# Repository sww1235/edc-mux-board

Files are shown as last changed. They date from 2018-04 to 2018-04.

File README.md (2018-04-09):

# EDC-MUX-Board

This is part of the [EDC harness
project](https://github.com/sww1235/edc-harness) and provides, audio and PTT
routing and control routing.

Will also potentially allow for audio priority ducking
via the [mixer](https://github.com/sww1235/portable-line-mixer).

All audio IO is done at consumer line level. (IO direction is referenced to MUX)

Connected headphones will accept this as there is also an integrated amplifier.
(Headset output)

Connected phones and radios inputting audio into the mux will also work fine as
they output line level. (Device input)

Electret microphones need a bias circuit and a preamp to boost their signal up
to line level. (headset input) as well as a capacitor to block the DC bias output

Connected phones and radios will need a pad circuit to reduce the line level
output to a microphone input as well as block dc output from phone/radio.
(Device Output) Resistor divider with ~40dB attenuation. Attenuation in dB = 20*
log10((R1 + R2)/R2). Also need resistance between bottom two sleeve contacts.

o-----^v^v^v--|---o
      R1      >
Line          < mic
          R2  >
              >
o-------------|---o

## Extra parts

-   EN3P8MCX switchcraft 8pin male panel mount connectors (use MPX 3d model)
-   EN3C8FCX switchcraft 8pin female cable connection
-   CARAEN3C8F07990 switchcraft 8pin female right angle pre-terminated cable
-   EN3CAPC  cord plug connector cover
-   EN3CAPX   panel mount connector cover
-   772-E25-103RYY1 norcomp db25 IP67 connector male
-   772-E25-203RYY1 norcomp db25 IP67 connector female (for panelmount)
-   967-025-010R011 norcomp db25 IP67 backshell for cable
-   SFP6725 norcomp adhesive seal db25 size
-   967-025-CAP norcomp ip67 sealing cap
-   160-067-004R034 norcomp db25 hardware kit
-   767KS1(X) 0.084 \[2.1\] id/od sealed locking power plug switchcraft
-   L722AS 0.08 \[2.0\] id/od sealed locking power jack switchcraft (these sizes are compatible with high amperage version
-   JCAP  power jack cover
-   35FM3AULS - Sealed locking 3.5mm panel mount jack switchcraft
-   35HDLBAU(S) 3.5mm sealed locking plug switchcraft (S=0.175 diameter cable, no S=0.29 diameter cable)
-   NE8FDX-P6-W IP rated ethercon connector Cat6A shielded neutrik
-   NE8MX6 Cat6A ethercon cable connector neutrik

## TODO

-   CODE
-   Case
    -   Change lid screws to M2.5
    -   Move Oring inside screw line (use same as on portable line mixer)
    -   weight reduction on chassis and lid. Shrink wall thickness to 0.125", leave ribs on base for stiffness
    -   leave sealing flange and ribs on lid
    -   leave connector sides full thickness

## Power Consumption

| Quantity | Description | Part Number | Individual Power Consumption |
|:---|:---|:---|:---|
| 3 | IO expanders | TCA9555 | 56uA \@5V |
| 6 | IO expanders | TCA9555 | 35uA \@2V5 |
| 24 | 8:1 Mux | ADG708 | 1uA max \@±2V5 (both rails) |
| 8 | 8:1 Mux | ADG708 | 1uA max \@5V |
| 3 | SPST switch | ADG715 | 25uA max \@±2V5 (both rails) |
| 4 | 4x SPDT switches | ADG734 | 1uA max \@±2V5 (both rails) |
| 72 | 4x op amp | OPA1604 | 2.8mA \@±12VA (both rails) |
| 21 | 2x op amp | OPA1602 | 2.6mA \@±12VA (both rails) |
| 12 | 2x digi pot | DS1882 | 1uA \@5VD, 2.5uA \@±5VA |
| 2 | OR gate | SN74ACT32 | 20uA \@5V |
| 2 | SPST switch | TS12A44514 | 0.2uA \@12V |
| Total | ±2V5 rail || 313uA (rounded ->) 0.5mA |
| Total | ±12VA rail || 256.2mA (rounded ->) 500mA |
| Total | ±5VA rail | | 30uA |
| Total | +5V rail | | 2\*2V5\* 0.5mA = 2.5mW \@5V = 0.5mA (assume at least 10mA) + </br>2\*5VA\* 30uA = 0.3mW \@5V = 60uA (assume at least 10mA) + </br>228uA -> 0.5mA </br> Sum = 0.5mA + 0.5mA + 60uA = 1.06mA (assume 30mA) = 6mA \@12V |
| Total | 12V+12VA rail | | 518.4mA (rounded ->) 1A (includes 2v5 and 5V conversions) |

## References

-   <http://www.epanorama.net/circuits/line_to_mic.html>
-   <http://www.n1gy.com/headset-adaptor.html>
-   <http://www.mobilinkd.com/category/hacking/>
-   <http://ham.stackexchange.com/questions/5244/2-pin-kenwood-to-sound-card-beofeng-uv-82hp-asus-xonar-essence-stx>
-   <http://uuki.kapsi.fi/dl/uv5r_spkmic.pdf>
-   <http://www.n1gy.com/headset-adaptor-for-kenwood--baofeng-and-wouxun-hts.html>
-   <http://electronics.stackexchange.com/questions/71335/how-to-amplify-electret-microphone-to-range-from-0-5v-with-bias-of-2-5v>
-   <https://www.invensense.com/wp-content/uploads/2015/02/Using-a-MEMS-Microphone-in-a-2-Wire-Microphone-Circuit.pdf>
-   <http://www.brenorbrophy.com/HG/head_set_ptt.htm>
-   <http://electronics.stackexchange.com/questions/25229/do-electret-condenser-microphones-require-phantom-power>
-   <http://electronics.stackexchange.com/questions/27452/coupling-electret-microphone-input-to-linear-audio-output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>
-   <http://electronics.stackexchange.com/questions/261258/electret-microphone-how-does-it-work?rq=1>
-   <https://forums.radioreference.com/radio-direction-finding-forum/297920-baofeng-foxhunt-transmitter.html>
-   <https://www.reddit.com/r/amateurradio/comments/2jd4wr/line_level_to_high_impedance_input/>
-   <http://electronics.stackexchange.com/questions/176941/microphone-connection-diagram>
-   <http://i.stack.imgur.com/BMmRJ.jpg>
-   <http://www.dotmana.com/weblog/wp-content/uploads/Kenwood-Ham-Speaker-Jack-Wiring-Schematic.png>
-   <http://forums.qrz.com/index.php?threads/aprsdroid-cable-for-rx-and-tx-on-baofeng-hts.486407/>
-   <http://n4ser.org/2015/aprs-tracker-the-project-phase-2-io/>
-   <http://ham.stackexchange.com/questions/5023/mic-ground-vs-ground>
-   <http://www.circuitbasics.com/how-to-hack-a-headphone-jack/>
-   <http://www.faberacoustical.com/forum/index.php/topic,123.0.html>
-   <http://electronics.stackexchange.com/questions/38452/electronic-aspects-of-iphone-3-5mm-audio-output>
-   <http://www.echoireland.com/Interface/PTT_to_Computer_Information.pdf>
-   <http://electronics.stackexchange.com/questions/22486/help-with-ptt-circuit-for-icom-radio>
-   <http://electronics.stackexchange.com/questions/176442/what-is-the-wiring-for-a-pull-down-resistor-on-the-or-gate>

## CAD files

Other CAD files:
case/edc-mux-board-housing.FCStd

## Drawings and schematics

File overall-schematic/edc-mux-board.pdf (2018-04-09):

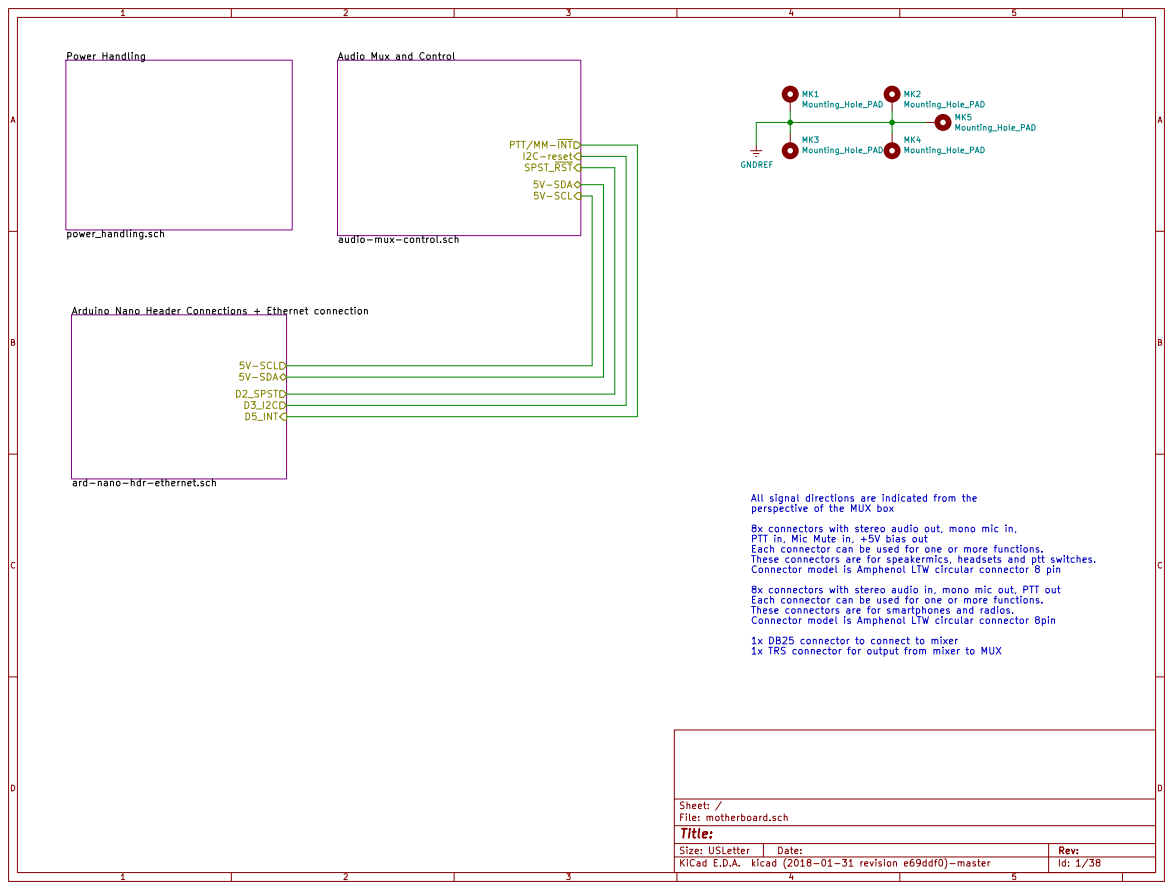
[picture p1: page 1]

Audio Mux and Control audio-mux-control.sch

Arduino Nano Header Connections + Ethernet connection

ard-nano-hdr-ethernet.sch

All signal directions are indicated from the
perspective of the MUX box
8x connectors with stereo audio out, mono mic in,
PTT in, Mic Mute in, +5V bias out Each connector can be used for one or more functions. These connectors are for speakermics, headsets and ptt switches.

Connector model is Amphenol LTW circular connector 8 pin
8x connectors with stereo audio in, mono mic out, PTT out Each connector can be used for one or more functions. These connectors are for smartphones and radios.

Connector model is Amphenol LTW circular connector 8pin
1x DB25 connector to connect to mixer 1x TRS connector for output from mixer to MUX

Id: 1/38 Title: File: motherboard.sch Sheet: /

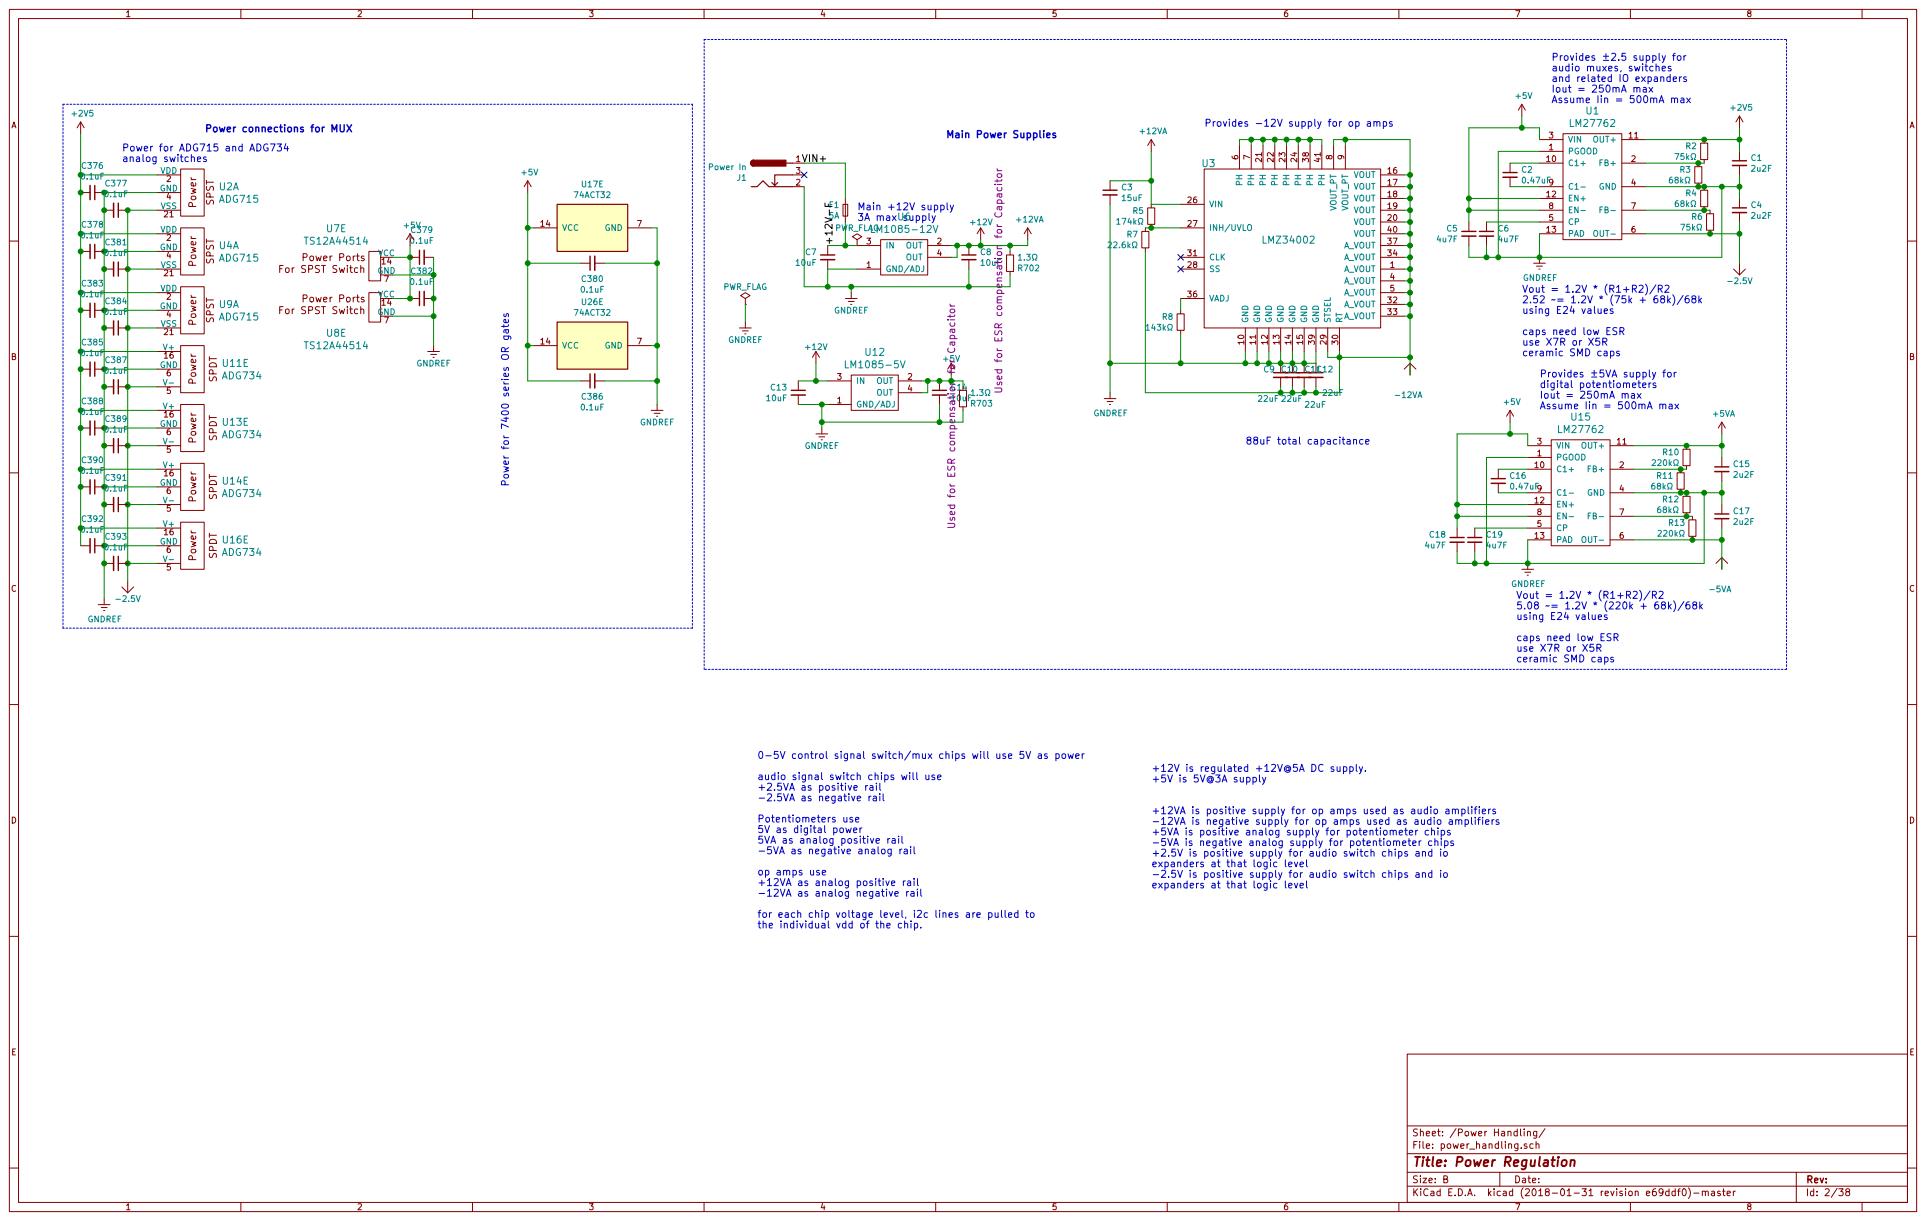
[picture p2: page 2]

Provides ±2.5 supply for
audio muxes, switches
and related IO expanders
Iout = 250mA max Assume Iin = 500mA max Vout = 1.2V * (R1+R2)/R2

Provides -12V supply for op amps R702

Iout = 250mA max Assume Iin = 500mA max Power for ADG715 and ADG734
analog switches

0.1uF C377 0.1uF C385 | 2VSS

Vout = 1.2V * (R1+R2)/R2
using E24 values
caps need low ESR
use X7R or X5R
ceramic SMD caps
Provides ±5VA supply for
digital potentiometers

0.1uF C387 | 21 GND

1.3 Used for ESR compensation for Capacitor

0.1uF C390 | 16V-5 GND

16V-5 GND

0-5V control signal switch/mux chips will use 5V as power
audio signal switch chips will use
+2.5VA as positive rail
-2.5VA as negative rail Potentiometers use 5V as digital power

+12V is regulated +12V@5A DC supply.
+5V is 5V@3A supply

+12VA is positive supply for op amps used as audio amplifiers
-12VA is negative supply for op amps used as audio amplifiers
+5VA is positive analog supply for potentiometer chips
-5VA is negative analog supply for potentiometer chips
+2.5V is positive supply for audio switch chips and io
expanders at that logic level
-2.5V is positive supply for audio switch chips and io

5VA as analog positive rail
-5VA as negative analog rail op amps use +12VA as analog positive rail

-12VA as analog negative rail
for each chip voltage level, i2c lines are pulled to
the individual vdd of the chip.

Sheet: /Power Handling/
File: power_handling.sch
Id: 2/38 Title: Power Regulation

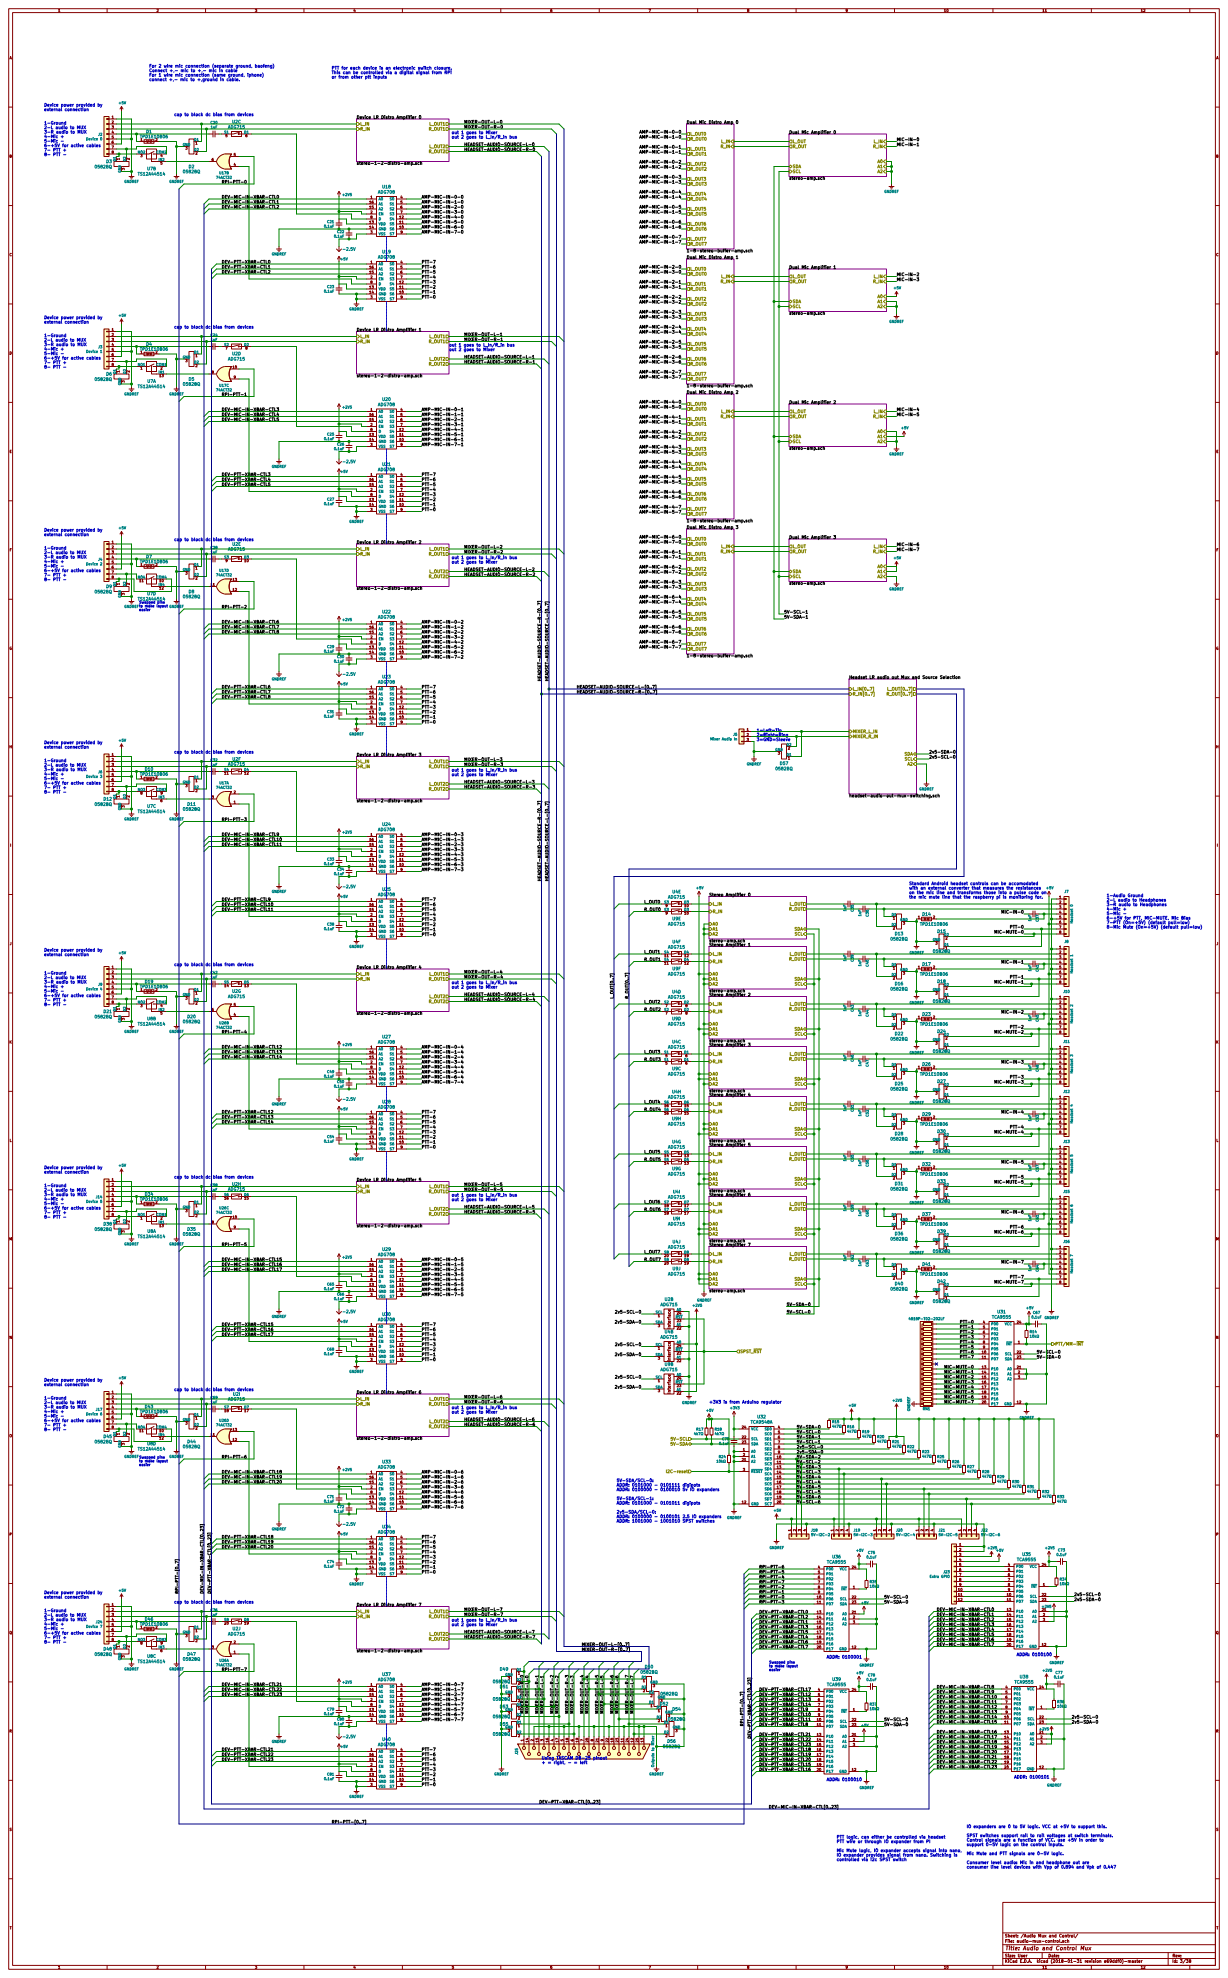
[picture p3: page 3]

For 2 wire mic connection (separate ground, baofeng)
Connect +,- mic to +,- mic in cable
For 1 wire mic connection (same ground, iphone)

or from other ptt inputs

cap to block dc bias from devices

MIXER-OUT-L-0
MIXER-OUT-R-0
out 1 goes to Mixer
out 2 goes to L_In/R_in bus
HEADSET-AUDIO-SOURCE-L-0
HEADSET-AUDIO-SOURCE-R-0

1-Ground
2-L audio to MUX
3-R audio to MUX
4-Mic +
5-Mic - 6-+5V for active cables 7- PTT +

Dual Mic Distro Amp 0

RPI-PTT-0 RPI-PTT-1 RPI-PTT-2 RPI-PTT-3 RPI-PTT-4 RPI-PTT-5 RPI-PTT-6 RPI-PTT-7 RPI-PTT-[0..7]

stereo-1-2-distro-amp.sch

DEV-MIC-IN-XBAR-CTL0
DEV-MIC-IN-XBAR-CTL1
DEV-MIC-IN-XBAR-CTL2

L_OUT7
R_OUT7
1-8-stereo-buffer-amp.sch
Dual Mic Distro Amp 1

out 1 goes to L_In/R_in bus
out 2 goes to Mixer

Dual Mic Distro Amp 2

DEV-MIC-IN-XBAR-CTL3
DEV-MIC-IN-XBAR-CTL4
DEV-MIC-IN-XBAR-CTL5

Dual Mic Distro Amp 3

MIXER-OUT-L-2
MIXER-OUT-R-2
HEADSET-AUDIO-SOURCE-L-2
HEADSET-AUDIO-SOURCE-R-2

AMP-MIC-IN-6-1
AMP-MIC-IN-7-1
HEADSET-AUDIO-SOURCE-R-[0..7] HEADSET-AUDIO-SOURCE-L-[0..7] HEADSET-AUDIO-SOURCE-L-[0..7] HEADSET-AUDIO-SOURCE-R-[0..7] HEADSET-AUDIO-SOURCE-R-[0..7]

Swapped pins
to make layout easier

DEV-MIC-IN-XBAR-CTL6
DEV-MIC-IN-XBAR-CTL7
DEV-MIC-IN-XBAR-CTL8

Headset LR audio out Mux and Source Selection

MIXER-OUT-L-3
MIXER-OUT-R-3
HEADSET-AUDIO-SOURCE-L-3
HEADSET-AUDIO-SOURCE-R-3

headset-audio-out-mux-switching.sch

DEV-MIC-IN-XBAR-CTL9
DEV-MIC-IN-XBAR-CTL10
DEV-MIC-IN-XBAR-CTL11

Standard Android headset controls can be accomodated with an external converter that measures the resistances on the mic line and transforms those into a pulse code on

MIC-MUTE-0 PTT-0 MIC-MUTE-1 PTT-1 MIC-MUTE-2 PTT-2 MIC-MUTE-3 PTT-3 MIC-MUTE-4 PTT-4 MIC-MUTE-5 PTT-5 MIC-MUTE-6 PTT-6 MIC-MUTE-7 PTT-7

1-Audio Ground
2-L audio to Headphones
3-R audio to Headphones 4-Mic +
5-Mic - 6-+5V for PTT, MIC-MUTE, Mic Bias
7-PTT (On=+5V) (default pull=low)
8-Mic Mute (On=+5V) (default pull=low)

MIXER-OUT-L-4
MIXER-OUT-R-4
HEADSET-AUDIO-SOURCE-L-4
HEADSET-AUDIO-SOURCE-R-4

DEV-MIC-IN-XBAR-CTL12
DEV-MIC-IN-XBAR-CTL13
DEV-MIC-IN-XBAR-CTL14

MIXER-OUT-L-5
MIXER-OUT-R-5
HEADSET-AUDIO-SOURCE-L-5
HEADSET-AUDIO-SOURCE-R-5
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

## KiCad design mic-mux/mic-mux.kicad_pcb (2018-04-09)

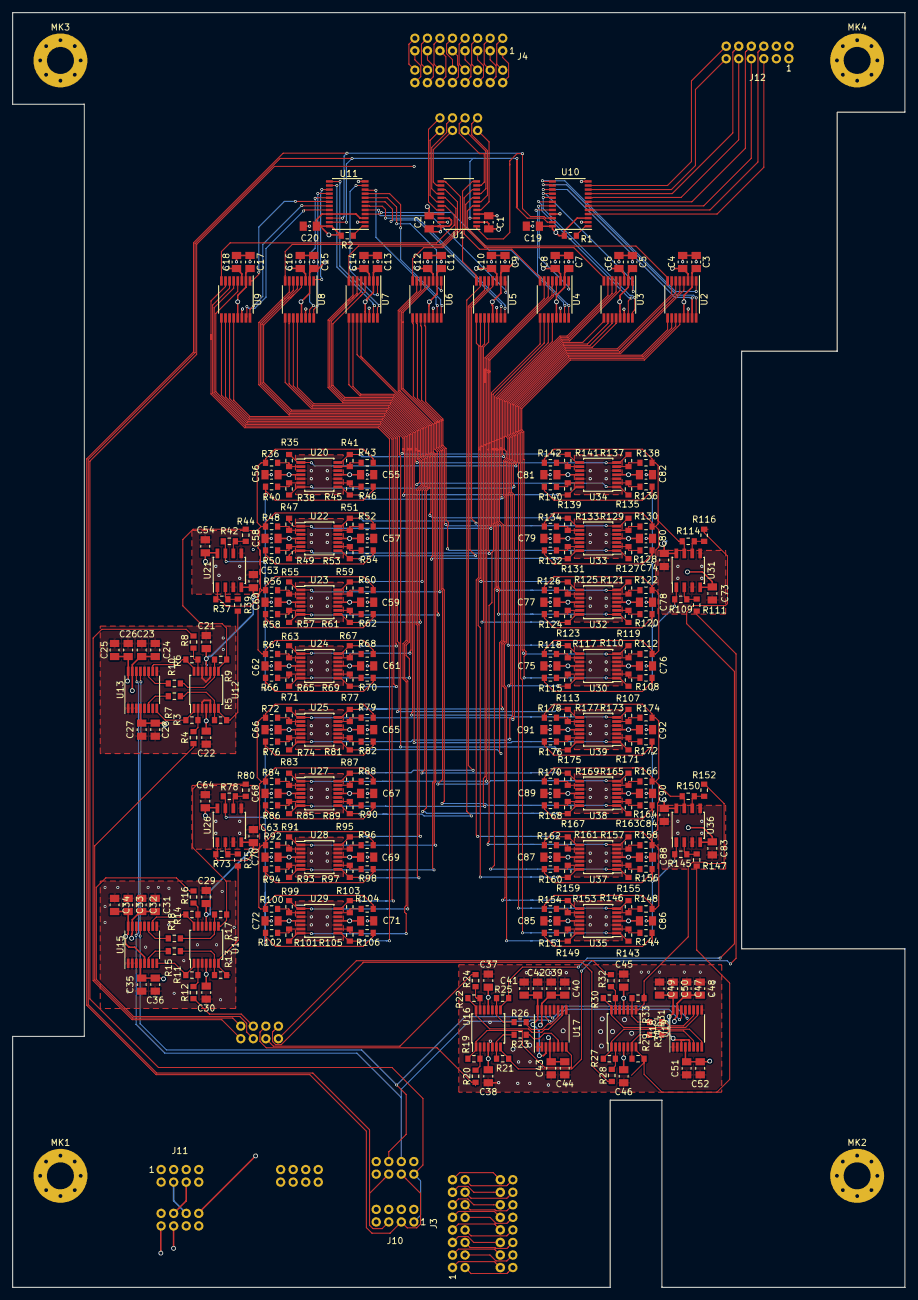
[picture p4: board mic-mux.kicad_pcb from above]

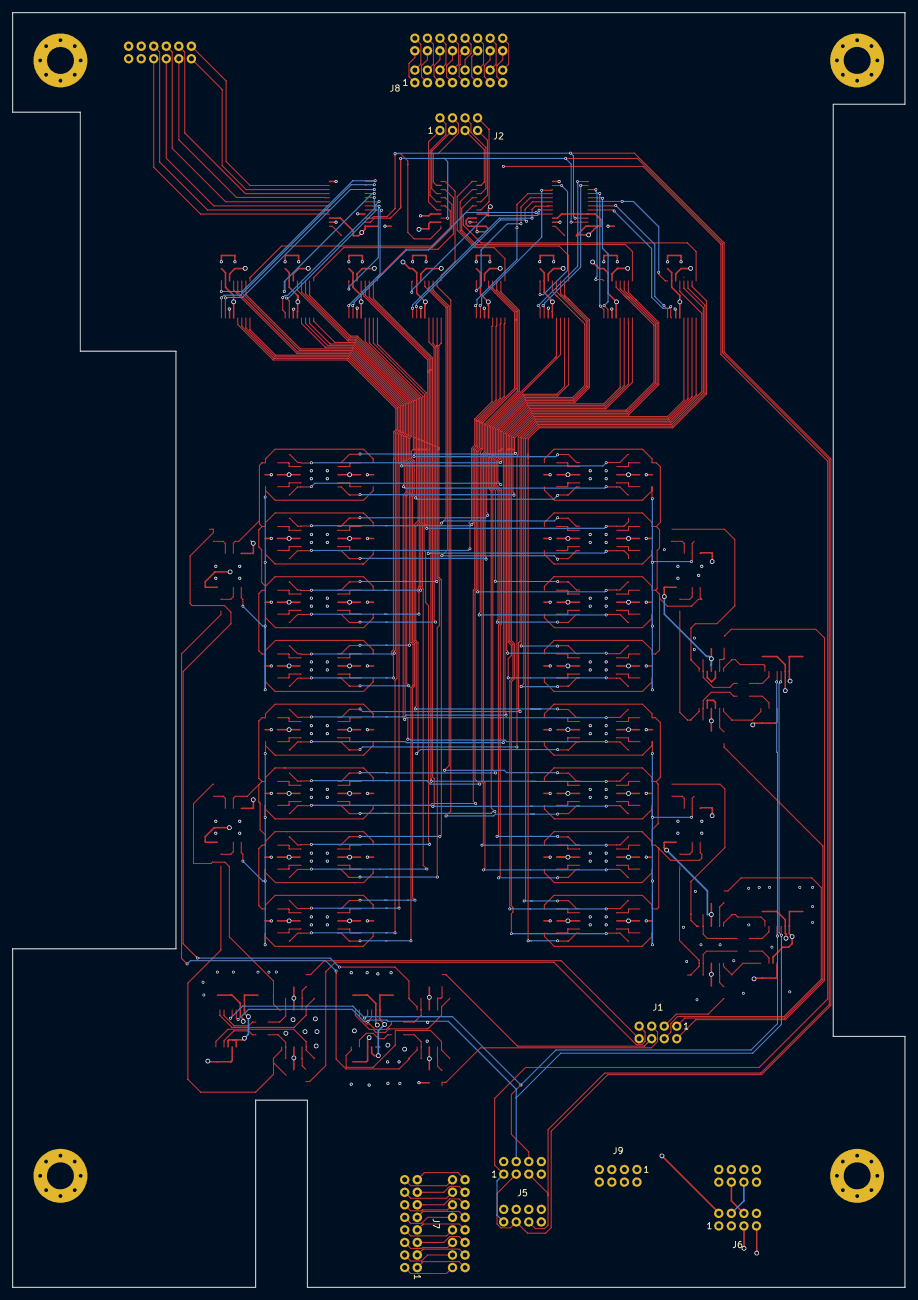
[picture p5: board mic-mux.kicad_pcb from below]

Board: 4 copper layers, 142.2 x 203.2 mm, 325 parts (7 on the bottom side), 287 nets.

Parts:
C1, C2, C3, C4, C5, C6, C7, C8, C9, C10, C11, C12, C13, C14, C15, C16, C17, C18, C19, C20, C21, C22, C24, C25, C28, C29, C30, C32, C33, C36, C37, C38, C40, C41, C44, C45, C46, C48, C49, C52, C53, C54, C55, C56, C57, C58, C59, C60, C61, C62, C63, C64, C65, C66, C67, C68, C69, C70, C71, C72, C73, C74, C75, C76, C77, C78, C79, C80, C81, C82, C83, C84, C85, C86, C87, C88, C89, C90, C91, C92: 0.1uF; C_0805_2012Metric_Pad1.15x1.50mm_HandSolder
C23, C26, C27, C31, C34, C35, C39, C42, C43, C47, C50, C51: 0.01uF; C_0805_2012Metric_Pad1.15x1.50mm_HandSolder
J1: MIC-IN; DF11-8DS-2DSA
J2: MIC-OUT; DF11-8DS-2DSA
J3: Headphone MUX Audio IN (Top-Male); DF11-16DP-2DSA
J4: Headphone MUX Audio OUT (Top-Male); DF11-16DP-2DSA
J5: I2C and Reset; DF11-8DS-2DSA
J6: Power In; DF11-8DS-2DSA
J7: Headphone MUX Audio IN (Bottom-Female); DF11-16DS-2DSA
J8: Headphone MUX Audio OUT (Bottom-Female); DF11-16DS-2DSA
J9: GND; DF11-8DS-2DSA
J10: I2C and Reset (Top-Male); DF11-8DP-2DSA
J11: Power Out (Top-Male); DF11-8DP-2DSA
J12: Extra GPIO; DF11-12DP-2DS
MK1, MK2, MK3, MK4: Mounting_Hole_PAD; MountingHole_4.3mm_M4_Pad_Via
R1, R2, R7, R10, R15, R18, R23, R26, R31, R34: 10kΩ; R_0603_1608Metric_Pad0.84x1.00mm_HandSolder
R3, R4, R5, R6, R8, R9, R11, R12, R13, R14, R16, R17, R19, R20, R21, R22, R24, R25, R27, R28, R29, R30, R32, R33, R35, R36, R37, R38, R39, R40, R41, R42, R43, R44, R45, R46, R47, R48, R49, R50, R51, R52, R53, R54, R55, R56, R57, R58, R59, R60, R61, R62, R63, R64, R65, R66, R67, R68, R69, R70, R71, R72, R73, R74, R75, R76, R77, R78, R79, R80, R81, R82, R83, R84, R85, R86, R87, R88, R89, R90, R91, R92, R93, R94, R95, R96, R97, R98, R99, R100, R101, R102, R103, R104, R105, R106, R107, R108, R109, R110, R111, R112, R113, R114, R115, R116, R117, R118, R119, R120, R121, R122, R123, R124, R125, R126, R127, R128, R129, R130, R131, R132, R133, R134, R135, R136, R137, R138, R139, R140, R141, R142, R143, R144, R145, R146, R147, R148, R149, R150, R151, R152, R153, R154, R155, R156, R157, R158, R159, R160, R161, R162, R163, R164, R165, R166, R167, R168, R169, R170, R171, R172, R173, R174, R175, R176, R177, R178: 100kΩ; R_0603_1608Metric_Pad0.84x1.00mm_HandSolder
U1: ADG715; TSSOP-24_4.4x7.8mm_P0.65mm
U2, U3, U4, U5, U6, U7, U8, U9: ADG708; TSSOP-16_4.4x5mm_P0.65mm
U10, U11: TCA9555; TSSOP-24_4.4x7.8mm_P0.65mm
U12, U14, U16, U18, U20, U22, U23, U24, U25, U27, U28, U29, U30, U32, U33, U34, U35, U37, U38, U39: OPA1604; TSSOP-14_4.4x5mm_P0.65mm
U13, U15, U17, U19: DS1882; TSSOP-16_4.4x5mm_P0.65mm
U21, U26, U31, U36: OPA1602; SOIC-8_3.9x4.9mm_P1.27mm

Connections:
+2V5: C1.2, C3.1, C5.1, C7.1, C9.1, C11.1, C13.1, C15.1, C17.1, C19.2, C20.2, J6.4, J11.4, J12.3, R1.1, R2.1, U1.2, U2.2, U2.13, U3.2, U3.13, U4.2, U4.13, U5.2, U5.13, U6.2, U6.13, U7.2, U7.13, U8.2, U8.13, U9.2, U9.13, U10.3, U10.24, U11.3, U11.21, U11.24
+5V: C25.2, C26.2, C33.2, C34.2, C41.2, C42.2, C49.2, C50.2, J6.1, J12.4, U13.16, U15.5, U15.16, U17.3, U17.16, U19.3, U19.5, U19.16
+5VA: C23.2, C24.2, C31.2, C32.2, C39.2, C40.2, C47.2, C48.2, J6.5, U13.15, U15.15, U17.15, U19.15
+12VA: C22.2, C30.2, C38.2, C46.2, C54.2, C56.2, C58.2, C60.2, C62.2, C64.2, C66.2, C68.2, C70.2, C72.2, C74.2, C76.2, C78.2, C80.2, C82.2, C84.2, C86.2, C88.2, C90.2, C92.2, J6.2, J11.2, U12.4, U14.4, U16.4, U18.4, U20.4, U21.8, U22.4, U23.4, U24.4, U25.4, U26.8, U27.4, U28.4, U29.4, U30.4, U31.8, U32.4, U33.4, U34.4, U35.4, U36.8, U37.4, U38.4, U39.4
-2.5V: C2.1, C4.2, C6.2, C8.2, C10.2, C12.2, C14.2, C16.2, C18.2, J6.6, J11.6, U1.21, U2.3, U3.3, U4.3, U5.3, U6.3, U7.3, U8.3, U9.3
-5VA: C27.2, C28.2, C35.2, C36.2, C43.2, C44.2, C51.2, C52.2, J6.7, U13.4, U15.4, U17.4, U19.4
-12VA: C21.2, C29.2, C37.2, C45.2, C53.2, C55.2, C57.2, C59.2, C61.2, C63.2, C65.2, C67.2, C69.2, C71.2, C73.2, C75.2, C77.2, C79.2, C81.2, C83.2, C85.2, C87.2, C89.2, C91.2, J6.8, J11.8, U12.11, U14.11, U16.11, U18.11, U20.11, U21.4, U22.11, U23.11, U24.11, U25.11, U26.4, U27.11, U28.11, U29.11, U30.11, U31.4, U32.11, U33.11, U34.11, U35.11, U36.4, U37.11, U38.11, U39.11
/2v5-SCL-0: J5.3, J10.3, U1.1, U10.22, U11.22
/2v5-SDA-0: J5.5, J10.5, U1.3, U10.23, U11.23
/5V-SCL-1: J5.4, U13.14, U15.14, U17.14, U19.14
/5V-SDA-1: J5.6, U13.13, U15.13, U17.13, U19.13
/MIC-IN0: J1.1, R4.2
/MIC-IN1: J1.2, R8.2
/MIC-IN2: J1.3, R12.2
/MIC-IN3: J1.4, R16.2
/MIC-IN4: J1.5, R20.2
/MIC-IN5: J1.6, R24.2
/MIC-IN6: J1.7, R28.2
/MIC-IN7: J1.8, R32.2
/MIC-OUT0: J2.1, U1.5
/MIC-OUT1: J2.2, U1.7
/MIC-OUT2: J2.3, U1.9
/MIC-OUT3: J2.4, U1.11
/MIC-OUT4: J2.5, U1.14
/MIC-OUT5: J2.6, U1.16
/MIC-OUT6: J2.7, U1.18
/MIC-OUT7: J2.8, U1.20
/Mic Mux and Control/AMP-MIC-IN-0-0: R35.1, U2.4, U20.1
/Mic Mux and Control/AMP-MIC-IN-0-1: R41.1, U3.4, U20.14
/Mic Mux and Control/AMP-MIC-IN-0-2: R47.1, U4.4, U22.1
/Mic Mux and Control/AMP-MIC-IN-0-3: R51.1, U5.4, U22.14
/Mic Mux and Control/AMP-MIC-IN-0-4: R55.1, U6.4, U23.1
/Mic Mux and Control/AMP-MIC-IN-0-5: R59.1, U7.4, U23.14
/Mic Mux and Control/AMP-MIC-IN-0-6: R63.1, U8.4, U24.1
/Mic Mux and Control/AMP-MIC-IN-0-7: R67.1, U9.4, U24.14
/Mic Mux and Control/AMP-MIC-IN-1-0: R38.1, U2.5, U20.7
/Mic Mux and Control/AMP-MIC-IN-1-1: R45.1, U3.5, U20.8
/Mic Mux and Control/AMP-MIC-IN-1-2: R49.1, U4.5, U22.7
/Mic Mux and Control/AMP-MIC-IN-1-3: R53.1, U5.5, U22.8
/Mic Mux and Control/AMP-MIC-IN-1-4: R57.1, U6.5, U23.7
/Mic Mux and Control/AMP-MIC-IN-1-5: R61.1, U7.5, U23.8
/Mic Mux and Control/AMP-MIC-IN-1-6: R65.1, U8.5, U24.7
/Mic Mux and Control/AMP-MIC-IN-1-7: R69.1, U9.5, U24.8
/Mic Mux and Control/AMP-MIC-IN-2-0: R71.1, U2.6, U25.1
/Mic Mux and Control/AMP-MIC-IN-2-1: R77.1, U3.6, U25.14
/Mic Mux and Control/AMP-MIC-IN-2-2: R83.1, U4.6, U27.1
/Mic Mux and Control/AMP-MIC-IN-2-3: R87.1, U5.6, U27.14
/Mic Mux and Control/AMP-MIC-IN-2-4: R91.1, U6.6, U28.1
/Mic Mux and Control/AMP-MIC-IN-2-5: R95.1, U7.6, U28.14
/Mic Mux and Control/AMP-MIC-IN-2-6: R99.1, U8.6, U29.1
/Mic Mux and Control/AMP-MIC-IN-2-7: R103.1, U9.6, U29.14
/Mic Mux and Control/AMP-MIC-IN-3-0: R74.1, U2.7, U25.7
/Mic Mux and Control/AMP-MIC-IN-3-1: R81.1, U3.7, U25.8
/Mic Mux and Control/AMP-MIC-IN-3-2: R85.1, U4.7, U27.7
/Mic Mux and Control/AMP-MIC-IN-3-3: R89.1, U5.7, U27.8
/Mic Mux and Control/AMP-MIC-IN-3-4: R93.1, U6.7, U28.7
/Mic Mux and Control/AMP-MIC-IN-3-5: R97.1, U7.7, U28.8
/Mic Mux and Control/AMP-MIC-IN-3-6: R101.1, U8.7, U29.7
/Mic Mux and Control/AMP-MIC-IN-3-7: R105.1, U9.7, U29.8
/Mic Mux and Control/AMP-MIC-IN-4-0: R107.1, U2.12, U30.1
/Mic Mux and Control/AMP-MIC-IN-4-1: R113.1, U3.12, U30.14
/Mic Mux and Control/AMP-MIC-IN-4-2: R119.1, U4.12, U32.1
/Mic Mux and Control/AMP-MIC-IN-4-3: R123.1, U5.12, U32.14
/Mic Mux and Control/AMP-MIC-IN-4-4: R127.1, U6.12, U33.1
/Mic Mux and Control/AMP-MIC-IN-4-5: R131.1, U7.12, U33.14
/Mic Mux and Control/AMP-MIC-IN-4-6: R135.1, U8.12, U34.1
/Mic Mux and Control/AMP-MIC-IN-4-7: R139.1, U9.12, U34.14
/Mic Mux and Control/AMP-MIC-IN-5-0: R110.1, U2.11, U30.7
/Mic Mux and Control/AMP-MIC-IN-5-1: R117.1, U3.11, U30.8
/Mic Mux and Control/AMP-MIC-IN-5-2: R121.1, U4.11, U32.7
/Mic Mux and Control/AMP-MIC-IN-5-3: R125.1, U5.11, U32.8
/Mic Mux and Control/AMP-MIC-IN-5-4: R129.1, U6.11, U33.7
/Mic Mux and Control/AMP-MIC-IN-5-5: R133.1, U7.11, U33.8
/Mic Mux and Control/AMP-MIC-IN-5-6: R137.1, U8.11, U34.7
/Mic Mux and Control/AMP-MIC-IN-5-7: R141.1, U9.11, U34.8
/Mic Mux and Control/AMP-MIC-IN-6-0: R143.1, U2.10, U35.1
/Mic Mux and Control/AMP-MIC-IN-6-1: R149.1, U3.10, U35.14
/Mic Mux and Control/AMP-MIC-IN-6-2: R155.1, U4.10, U37.1
/Mic Mux and Control/AMP-MIC-IN-6-3: R159.1, U5.10, U37.14
/Mic Mux and Control/AMP-MIC-IN-6-4: R163.1, U6.10, U38.1
/Mic Mux and Control/AMP-MIC-IN-6-5: R167.1, U7.10, U38.14
/Mic Mux and Control/AMP-MIC-IN-6-6: R171.1, U8.10, U39.1
/Mic Mux and Control/AMP-MIC-IN-6-7: R175.1, U9.10, U39.14
/Mic Mux and Control/AMP-MIC-IN-7-0: R146.1, U2.9, U35.7
/Mic Mux and Control/AMP-MIC-IN-7-1: R153.1, U3.9, U35.8
/Mic Mux and Control/AMP-MIC-IN-7-2: R157.1, U4.9, U37.7
/Mic Mux and Control/AMP-MIC-IN-7-3: R161.1, U5.9, U37.8
/Mic Mux and Control/AMP-MIC-IN-7-4: R165.1, U6.9, U38.7
/Mic Mux and Control/AMP-MIC-IN-7-5: R169.1, U7.9, U38.8
/Mic Mux and Control/AMP-MIC-IN-7-6: R173.1, U8.9, U39.7
/Mic Mux and Control/AMP-MIC-IN-7-7: R177.1, U9.9, U39.8
/Mic Mux and Control/DEV-MIC-IN-XBAR-CTL0: U2.1, U10.13
/Mic Mux and Control/DEV-MIC-IN-XBAR-CTL1: U2.16, U10.14
/Mic Mux and Control/DEV-MIC-IN-XBAR-CTL2: U2.15, U10.15
/Mic Mux and Control/DEV-MIC-IN-XBAR-CTL3: U3.1, U10.16
/Mic Mux and Control/DEV-MIC-IN-XBAR-CTL4: U3.16, U10.17
/Mic Mux and Control/DEV-MIC-IN-XBAR-CTL5: U3.15, U10.18
/Mic Mux and Control/DEV-MIC-IN-XBAR-CTL6: U4.1, U10.19
/Mic Mux and Control/DEV-MIC-IN-XBAR-CTL7: U4.16, U10.20
/Mic Mux and Control/DEV-MIC-IN-XBAR-CTL8: U4.15, U11.4
/Mic Mux and Control/DEV-MIC-IN-XBAR-CTL9: U5.1, U11.5
/Mic Mux and Control/DEV-MIC-IN-XBAR-CTL10: U5.16, U11.6
/Mic Mux and Control/DEV-MIC-IN-XBAR-CTL11: U5.15, U11.7
/Mic Mux and Control/DEV-MIC-IN-XBAR-CTL12: U6.1, U11.8
/Mic Mux and Control/DEV-MIC-IN-XBAR-CTL13: U6.16, U11.9
/Mic Mux and Control/DEV-MIC-IN-XBAR-CTL14: U6.15, U11.10
/Mic Mux and Control/DEV-MIC-IN-XBAR-CTL15: U7.1, U11.11
/Mic Mux and Control/DEV-MIC-IN-XBAR-CTL16: U7.16, U11.13
/Mic Mux and Control/DEV-MIC-IN-XBAR-CTL17: U7.15, U11.14
/Mic Mux and Control/DEV-MIC-IN-XBAR-CTL18: U8.1, U11.15
/Mic Mux and Control/DEV-MIC-IN-XBAR-CTL19: U8.16, U11.16
/Mic Mux and Control/DEV-MIC-IN-XBAR-CTL20: U8.15, U11.17
/Mic Mux and Control/DEV-MIC-IN-XBAR-CTL21: U9.1, U11.18
/Mic Mux and Control/DEV-MIC-IN-XBAR-CTL22: U9.16, U11.19
/Mic Mux and Control/DEV-MIC-IN-XBAR-CTL23: U9.15, U11.20
/Mic Mux and Control/Dual Mic Distro Amp 0/L_Distro_Bus: R36.2, R37.1, R43.2, R48.2, R52.2, R56.2, R60.2, R64.2, R68.2, U21.1
/Mic Mux and Control/Dual Mic Distro Amp 0/L_IN: R5.1, R39.2, U12.7
/Mic Mux and Control/Dual Mic Distro Amp 0/R_Distro_Bus: R40.2, R42.1, R46.2, R50.2, R54.2, R58.2, R62.2, R66.2, R70.2, U21.7
/Mic Mux and Control/Dual Mic Distro Amp 0/R_IN: R9.1, R44.2, U12.8
/Mic Mux and Control/Dual Mic Distro Amp 1/L_Distro_Bus: R72.2, R73.1, R79.2, R84.2, R88.2, R92.2, R96.2, R100.2, R104.2, U26.1
/Mic Mux and Control/Dual Mic Distro Amp 1/L_IN: R13.1, R75.2, U14.7
/Mic Mux and Control/Dual Mic Distro Amp 1/R_Distro_Bus: R76.2, R78.1, R82.2, R86.2, R90.2, R94.2, R98.2, R102.2, R106.2, U26.7
/Mic Mux and Control/Dual Mic Distro Amp 1/R_IN: R17.1, R80.2, U14.8
/Mic Mux and Control/Dual Mic Distro Amp 2/L_Distro_Bus: R108.2, R109.1, R115.2, R120.2, R124.2, R128.2, R132.2, R136.2, R140.2, U31.1
/Mic Mux and Control/Dual Mic Distro Amp 2/L_IN: R21.1, R111.2, U16.7
/Mic Mux and Control/Dual Mic Distro Amp 2/R_Distro_Bus: R112.2, R114.1, R118.2, R122.2, R126.2, R130.2, R134.2, R138.2, R142.2, U31.7
/Mic Mux and Control/Dual Mic Distro Amp 2/R_IN: R25.1, R116.2, U16.8
/Mic Mux and Control/Dual Mic Distro Amp 3/L_Distro_Bus: R144.2, R145.1, R151.2, R156.2, R160.2, R164.2, R168.2, R172.2, R176.2, U36.1
/Mic Mux and Control/Dual Mic Distro Amp 3/L_IN: R29.1, R147.2, U18.7
/Mic Mux and Control/Dual Mic Distro Amp 3/R_Distro_Bus: R148.2, R150.1, R154.2, R158.2, R162.2, R166.2, R170.2, R174.2, R178.2, U36.7
/Mic Mux and Control/Dual Mic Distro Amp 3/R_IN: R33.1, R152.2, U18.8
/SPST-~RST: J5.1, J10.1, U1.23
GNDREF: C1.1, C2.2, C3.2, C4.1, C5.2, C6.1, C7.2, C8.1, C9.2, C10.1, C11.2, C12.1, C13.2, C14.1, C15.2, C16.1, C17.2, C18.1, C19.1, C20.1, C21.1, C22.1, C23.1, C24.1, C25.1, C26.1, C27.1, C28.1, C29.1, C30.1, C31.1, C32.1, C33.1, C34.1, C35.1, C36.1, C37.1, C38.1, C39.1, C40.1, C41.1, C42.1, C43.1, C44.1, C45.1, C46.1, C47.1, C48.1, C49.1, C50.1, C51.1, C52.1, C53.1, C54.1, C55.1, C56.1, C57.1, C58.1, C59.1, C60.1, C61.1, C62.1, C63.1, C64.1, C65.1, C66.1, C67.1, C68.1, C69.1, C70.1, C71.1, C72.1, C73.1, C74.1, C75.1, C76.1, C77.1, C78.1, C79.1, C80.1, C81.1, C82.1, C83.1, C84.1, C85.1, C86.1, C87.1, C88.1, C89.1, C90.1, C91.1, C92.1, J5.2, J5.7, J5.8, J6.3, J9.1, J9.2, J9.3, J9.4, J9.5, J9.6, J9.7, J9.8, J10.2, J10.4, J10.6, J10.7, J10.8, J11.1, J11.3, J11.5, J11.7, J12.1, J12.2, MK1.1, MK2.1, MK3.1, MK4.1, U1.4, U1.22, U1.24, U2.14, U3.14, U4.14, U5.14, U6.14, U7.14, U8.14, U9.14, U10.2, U10.12, U10.21, U11.2, U11.12, U12.3, U12.5, U12.10, U12.12, U13.1, U13.2, U13.3, U13.5, U13.7, U13.9, U13.12, U14.3, U14.5, U14.10, U14.12, U15.1, U15.2, U15.3, U15.7, U15.9, U15.12, U16.3, U16.5, U16.10, U16.12, U17.1, U17.2, U17.5, U17.7, U17.9, U17.12, U18.3, U18.5, U18.10, U18.12, U19.1, U19.2, U19.7, U19.9, U19.12, U20.3, U20.5, U20.10, U20.12, U21.3, U21.5, U22.3, U22.5, U22.10, U22.12, U23.3, U23.5, U23.10, U23.12, U24.3, U24.5, U24.10, U24.12, U25.3, U25.5, U25.10, U25.12, U26.3, U26.5, U27.3, U27.5, U27.10, U27.12, U28.3, U28.5, U28.10, U28.12, U29.3, U29.5, U29.10, U29.12, U30.3, U30.5, U30.10, U30.12, U31.3, U31.5, U32.3, U32.5, U32.10, U32.12, U33.3, U33.5, U33.10, U33.12, U34.3, U34.5, U34.10, U34.12, U35.3, U35.5, U35.10, U35.12, U36.3, U36.5, U37.3, U37.5, U37.10, U37.12, U38.3, U38.5, U38.10, U38.12, U39.3, U39.5, U39.10, U39.12
unnamed: J3.1, J7.1
unnamed: J3.2, J7.2
unnamed: J3.3, J7.3
unnamed: J3.4, J7.4
unnamed: J3.5, J7.5
unnamed: J3.6, J7.6
unnamed: J3.7, J7.7
unnamed: J3.8, J7.8
unnamed: J3.9, J7.9
unnamed: J3.10, J7.10
unnamed: J3.11, J7.11
unnamed: J3.12, J7.12
unnamed: J3.13, J7.13
unnamed: J3.14, J7.14
unnamed: J3.15, J7.15
unnamed: J3.16, J7.16
unnamed: J4.1, J8.1
unnamed: J4.2, J8.2
unnamed: J4.3, J8.3
unnamed: J4.4, J8.4
unnamed: J4.5, J8.5
unnamed: J4.6, J8.6
unnamed: J4.7, J8.7
unnamed: J4.8, J8.8
unnamed: J4.9, J8.9
unnamed: J4.10, J8.10
unnamed: J4.11, J8.11
unnamed: J4.12, J8.12
unnamed: J4.13, J8.13
unnamed: J4.14, J8.14
unnamed: J4.15, J8.15
unnamed: J4.16, J8.16
unnamed: J12.5, U10.4
unnamed: J12.6, U10.5
unnamed: J12.7, U10.6
unnamed: J12.8, U10.7
unnamed: J12.9, U10.8
unnamed: J12.10, U10.9
unnamed: J12.11, U10.10
unnamed: J12.12, U10.11
unnamed: R1.2, U10.1
unnamed: R2.2, U11.1
unnamed: R3.1, U12.1, U13.8
unnamed: R3.2, R4.1, U12.2
unnamed: R5.2, R7.1, U12.6
unnamed: R6.1, U12.14, U13.10
unnamed: R6.2, R8.1, U12.13
unnamed: R7.2, U13.6
unnamed: R9.2, R10.1, U12.9
unnamed: R10.2, U13.11
unnamed: R11.1, U14.1, U15.8
unnamed: R11.2, R12.1, U14.2
unnamed: R13.2, R15.1, U14.6
unnamed: R14.1, U14.14, U15.10
unnamed: R14.2, R16.1, U14.13
unnamed: R15.2, U15.6
unnamed: R17.2, R18.1, U14.9
unnamed: R18.2, U15.11
unnamed: R19.1, U16.1, U17.8
unnamed: R19.2, R20.1, U16.2
unnamed: R21.2, R23.1, U16.6
unnamed: R22.1, U16.14, U17.10
unnamed: R22.2, R24.1, U16.13
unnamed: R23.2, U17.6
unnamed: R25.2, R26.1, U16.9
unnamed: R26.2, U17.11
unnamed: R27.1, U18.1, U19.8
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

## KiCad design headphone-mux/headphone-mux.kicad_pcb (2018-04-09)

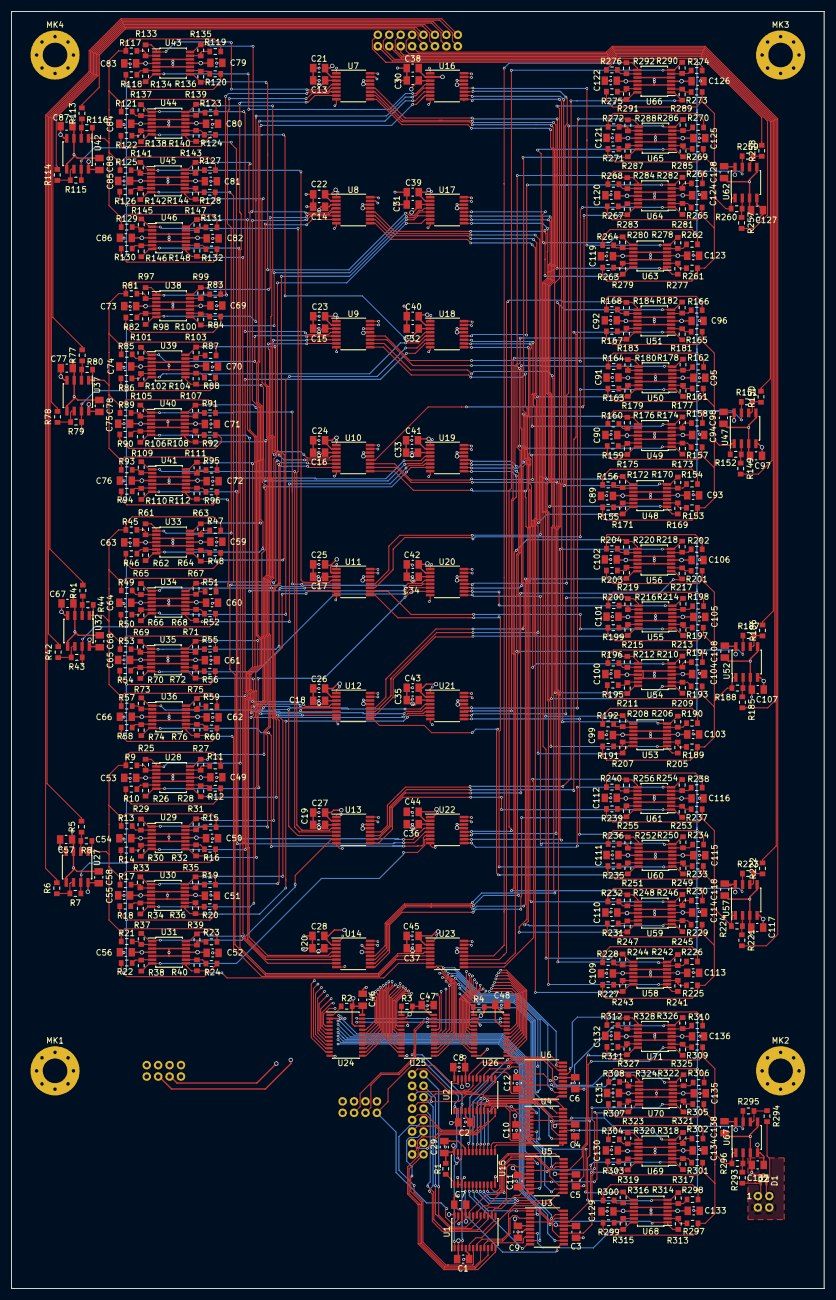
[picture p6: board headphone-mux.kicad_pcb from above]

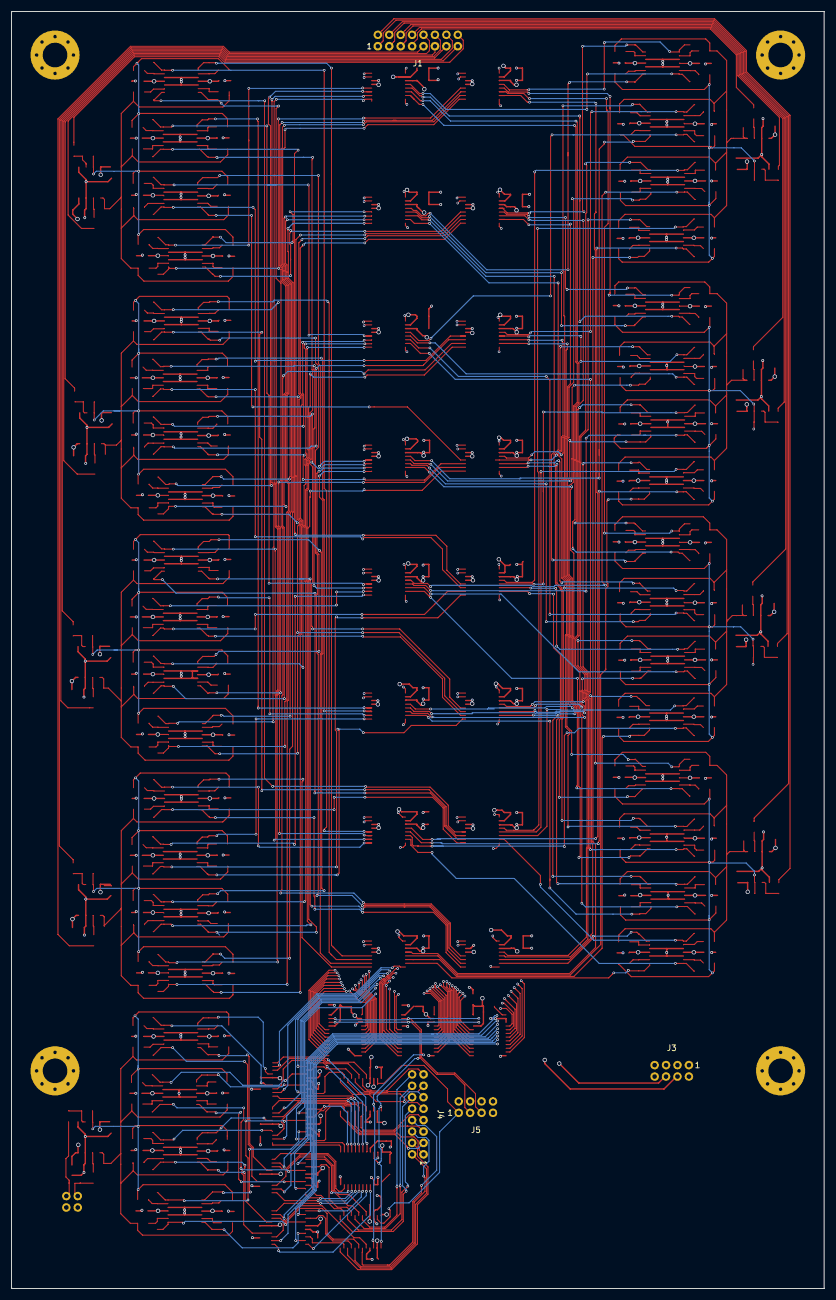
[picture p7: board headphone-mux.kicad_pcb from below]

Board: 4 copper layers, 142.2 x 223.5 mm, 547 parts (4 on the bottom side), 466 nets.

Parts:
C1, C2, C3, C4, C5, C6, C7, C8, C9, C10, C11, C12, C13, C14, C15, C16, C17, C18, C19, C20, C21, C22, C23, C24, C25, C26, C27, C28, C29, C30, C31, C32, C33, C34, C35, C36, C37, C38, C39, C40, C41, C42, C43, C44, C45, C46, C47, C48, C49, C50, C51, C52, C53, C54, C55, C56, C57, C58, C59, C60, C61, C62, C63, C64, C65, C66, C67, C68, C69, C70, C71, C72, C73, C74, C75, C76, C77, C78, C79, C80, C81, C82, C83, C84, C85, C86, C87, C88, C89, C90, C91, C92, C93, C94, C95, C96, C97, C98, C99, C100, C101, C102, C103, C104, C105, C106, C107, C108, C109, C110, C111, C112, C113, C114, C115, C116, C117, C118, C119, C120, C121, C122, C123, C124, C125, C126, C127, C128, C129, C130, C131, C132, C133, C134, C135, C136, C137, C138: 0.1uF; C_0805_2012Metric_Pad1.15x1.50mm_HandSolder
D1: 0582BQ; SC-75_3L
J1: Audio-Input; DF11-16DS-2DSA
J2: Mixer Audio In; DF11-4DP-2DSA
J3: Power Input; DF11-8DS-2DSA
J4: Audio Output; DF11-16DS-2DSA
J5: I2C and Reset; DF11-8DS-2DSA
MK1, MK2, MK3, MK4: Mounting_Hole_PAD; MountingHole_4.3mm_M4_Pad_Via
R1, R2, R3, R4: 10kΩ; R_0603_1608Metric_Pad0.84x1.00mm_HandSolder
R5, R6, R7, R8, R9, R10, R11, R12, R13, R14, R15, R16, R17, R18, R19, R20, R21, R22, R23, R24, R25, R26, R27, R28, R29, R30, R31, R32, R33, R34, R35, R36, R37, R38, R39, R40, R41, R42, R43, R44, R45, R46, R47, R48, R49, R50, R51, R52, R53, R54, R55, R56, R57, R58, R59, R60, R61, R62, R63, R64, R65, R66, R67, R68, R69, R70, R71, R72, R73, R74, R75, R76, R77, R78, R79, R80, R81, R82, R83, R84, R85, R86, R87, R88, R89, R90, R91, R92, R93, R94, R95, R96, R97, R98, R99, R100, R101, R102, R103, R104, R105, R106, R107, R108, R109, R110, R111, R112, R113, R114, R115, R116, R117, R118, R119, R120, R121, R122, R123, R124, R125, R126, R127, R128, R129, R130, R131, R132, R133, R134, R135, R136, R137, R138, R139, R140, R141, R142, R143, R144, R145, R146, R147, R148, R149, R150, R151, R152, R153, R154, R155, R156, R157, R158, R159, R160, R161, R162, R163, R164, R165, R166, R167, R168, R169, R170, R171, R172, R173, R174, R175, R176, R177, R178, R179, R180, R181, R182, R183, R184, R185, R186, R187, R188, R189, R190, R191, R192, R193, R194, R195, R196, R197, R198, R199, R200, R201, R202, R203, R204, R205, R206, R207, R208, R209, R210, R211, R212, R213, R214, R215, R216, R217, R218, R219, R220, R221, R222, R223, R224, R225, R226, R227, R228, R229, R230, R231, R232, R233, R234, R235, R236, R237, R238, R239, R240, R241, R242, R243, R244, R245, R246, R247, R248, R249, R250, R251, R252, R253, R254, R255, R256, R257, R258, R259, R260, R261, R262, R263, R264, R265, R266, R267, R268, R269, R270, R271, R272, R273, R274, R275, R276, R277, R278, R279, R280, R281, R282, R283, R284, R285, R286, R287, R288, R289, R290, R291, R292, R293, R294, R295, R296, R297, R298, R299, R300, R301, R302, R303, R304, R305, R306, R307, R308, R309, R310, R311, R312, R313, R314, R315, R316, R317, R318, R319, R320, R321, R322, R323, R324, R325, R326, R327, R328: 100kΩ; R_0603_1608Metric_Pad0.84x1.00mm_HandSolder
U1, U2: ADG715; TSSOP-24_4.4x7.8mm_P0.65mm
U3, U4, U5, U6: ADG734; TSSOP-20_4.4x6.5mm_P0.65mm
U7, U8, U9, U10, U11, U12, U13, U14, U16, U17, U18, U19, U20, U21, U22, U23: ADG708; TSSOP-16_4.4x5mm_P0.65mm
U15, U24, U25, U26: TCA9555; TSSOP-24_4.4x7.8mm_P0.65mm
U27, U32, U37, U42, U47, U52, U57, U62, U67: OPA1602; SOIC-8_3.9x4.9mm_P1.27mm
U28, U29, U30, U31, U33, U34, U35, U36, U38, U39, U40, U41, U43, U44, U45, U46, U48, U49, U50, U51, U53, U54, U55, U56, U58, U59, U60, U61, U63, U64, U65, U66, U68, U69, U70, U71: OPA1604; TSSOP-14_4.4x5mm_P0.65mm

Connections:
+2V5: C1.2, C2.2, C3.2, C4.2, C5.2, C6.2, C21.1, C22.1, C23.1, C24.1, C25.1, C26.1, C27.1, C28.1, C29.2, C38.1, C39.1, C40.1, C41.1, C42.1, C43.1, C44.1, C45.1, C46.2, C47.2, C48.2, J3.4, R1.1, R2.1, R3.1, R4.1, U1.2, U1.24, U2.2, U2.22, U3.16, U4.16, U5.16, U6.16, U7.2, U7.13, U8.2, U8.13, U9.2, U9.13, U10.2, U10.13, U11.2, U11.13, U12.2, U12.13, U13.2, U13.13, U14.2, U14.13, U15.24, U16.2, U16.13, U17.2, U17.13, U18.2, U18.13, U19.2, U19.13, U20.2, U20.13, U21.2, U21.13, U22.2, U22.13, U23.2, U23.13, U24.21, U24.24, U25.2, U25.24, U26.2, U26.21, U26.24
+12VA: C53.2, C54.2, C55.2, C56.2, C58.2, C63.2, C64.2, C65.2, C66.2, C68.2, C73.2, C74.2, C75.2, C76.2, C78.2, C83.2, C84.2, C85.2, C86.2, C88.2, C93.2, C94.2, C95.2, C96.2, C98.2, C103.2, C104.2, C105.2, C106.2, C108.2, C113.2, C114.2, C115.2, C116.2, C118.2, C123.2, C124.2, C125.2, C126.2, C128.2, C133.2, C134.2, C135.2, C136.2, C138.2, J3.2, U27.8, U28.4, U29.4, U30.4, U31.4, U32.8, U33.4, U34.4, U35.4, U36.4, U37.8, U38.4, U39.4, U40.4, U41.4, U42.8, U43.4, U44.4, U45.4, U46.4, U47.8, U48.4, U49.4, U50.4, U51.4, U52.8, U53.4, U54.4, U55.4, U56.4, U57.8, U58.4, U59.4, U60.4, U61.4, U62.8, U63.4, U64.4, U65.4, U66.4, U67.8, U68.4, U69.4, U70.4, U71.4
-2.5V: C7.1, C8.1, C9.1, C10.1, C11.1, C12.1, C13.2, C14.2, C15.2, C16.2, C17.2, C18.2, C19.2, C20.2, C30.2, C31.2, C32.2, C33.2, C34.2, C35.2, C36.2, C37.2, J3.6, U1.21, U2.21, U3.5, U4.5, U5.5, U6.5, U7.3, U8.3, U9.3, U10.3, U11.3, U12.3, U13.3, U14.3, U16.3, U17.3, U18.3, U19.3, U20.3, U21.3, U22.3, U23.3
-12VA: C49.2, C50.2, C51.2, C52.2, C57.2, C59.2, C60.2, C61.2, C62.2, C67.2, C69.2, C70.2, C71.2, C72.2, C77.2, C79.2, C80.2, C81.2, C82.2, C87.2, C89.2, C90.2, C91.2, C92.2, C97.2, C99.2, C100.2, C101.2, C102.2, C107.2, C109.2, C110.2, C111.2, C112.2, C117.2, C119.2, C120.2, C121.2, C122.2, C127.2, C129.2, C130.2, C131.2, C132.2, C137.2, J3.8, U27.4, U28.11, U29.11, U30.11, U31.11, U32.4, U33.11, U34.11, U35.11, U36.11, U37.4, U38.11, U39.11, U40.11, U41.11, U42.4, U43.11, U44.11, U45.11, U46.11, U47.4, U48.11, U49.11, U50.11, U51.11, U52.4, U53.11, U54.11, U55.11, U56.11, U57.4, U58.11, U59.11, U60.11, U61.11, U62.4, U63.11, U64.11, U65.11, U66.11, U67.4, U68.11, U69.11, U70.11, U71.11
/2v5-SCL-0: J5.3, U1.1, U2.1, U15.22, U24.22, U25.22, U26.22
/2v5-SDA-0: J5.5, U1.3, U2.3, U15.23, U24.23, U25.23, U26.23
/HEADSET-AUDIO-SOURCE-L-0: J1.1, R5.2
/HEADSET-AUDIO-SOURCE-L-1: J1.3, R41.2
/HEADSET-AUDIO-SOURCE-L-2: J1.5, R77.2
/HEADSET-AUDIO-SOURCE-L-3: J1.7, R113.2
/HEADSET-AUDIO-SOURCE-L-4: J1.15, R257.2
/HEADSET-AUDIO-SOURCE-L-5: J1.13, R149.2
/HEADSET-AUDIO-SOURCE-L-6: J1.11, R185.2
/HEADSET-AUDIO-SOURCE-L-7: J1.9, R221.2
/HEADSET-AUDIO-SOURCE-R-0: J1.2, R6.2
/HEADSET-AUDIO-SOURCE-R-1: J1.4, R42.2
/HEADSET-AUDIO-SOURCE-R-2: J1.6, R78.2
/HEADSET-AUDIO-SOURCE-R-3: J1.8, R114.2
/HEADSET-AUDIO-SOURCE-R-4: J1.16, R258.2
/HEADSET-AUDIO-SOURCE-R-5: J1.14, R150.2
/HEADSET-AUDIO-SOURCE-R-6: J1.12, R186.2
/HEADSET-AUDIO-SOURCE-R-7: J1.10, R222.2
/Headset Audio Out Mux Switching/DEV0_L_0: R25.1, U7.7, U28.1
/Headset Audio Out Mux Switching/DEV0_L_1: R27.1, U8.7, U28.14
/Headset Audio Out Mux Switching/DEV0_L_2: R29.1, U9.7, U29.1
/Headset Audio Out Mux Switching/DEV0_L_3: R31.1, U10.7, U29.14
/Headset Audio Out Mux Switching/DEV0_L_4: R33.1, U11.7, U30.1
/Headset Audio Out Mux Switching/DEV0_L_5: R35.1, U12.7, U30.14
/Headset Audio Out Mux Switching/DEV0_L_6: R37.1, U13.7, U31.1
/Headset Audio Out Mux Switching/DEV0_L_7: R39.1, U14.7, U31.14
/Headset Audio Out Mux Switching/DEV0_R_0: R26.1, U16.7, U28.7
/Headset Audio Out Mux Switching/DEV0_R_1: R28.1, U17.7, U28.8
/Headset Audio Out Mux Switching/DEV0_R_2: R30.1, U18.7, U29.7
/Headset Audio Out Mux Switching/DEV0_R_3: R32.1, U19.7, U29.8
/Headset Audio Out Mux Switching/DEV0_R_4: R34.1, U20.7, U30.7
/Headset Audio Out Mux Switching/DEV0_R_5: R36.1, U21.7, U30.8
/Headset Audio Out Mux Switching/DEV0_R_6: R38.1, U22.7, U31.7
/Headset Audio Out Mux Switching/DEV0_R_7: R40.1, U23.7, U31.8
/Headset Audio Out Mux Switching/DEV1_L_0: R61.1, U7.6, U33.1
/Headset Audio Out Mux Switching/DEV1_L_1: R63.1, U8.6, U33.14
/Headset Audio Out Mux Switching/DEV1_L_2: R65.1, U9.6, U34.1
/Headset Audio Out Mux Switching/DEV1_L_3: R67.1, U10.6, U34.14
/Headset Audio Out Mux Switching/DEV1_L_4: R69.1, U11.6, U35.1
/Headset Audio Out Mux Switching/DEV1_L_5: R71.1, U12.6, U35.14
/Headset Audio Out Mux Switching/DEV1_L_6: R73.1, U13.6, U36.1
/Headset Audio Out Mux Switching/DEV1_L_7: R75.1, U14.6, U36.14
/Headset Audio Out Mux Switching/DEV1_R_0: R62.1, U16.6, U33.7
/Headset Audio Out Mux Switching/DEV1_R_1: R64.1, U17.6, U33.8
/Headset Audio Out Mux Switching/DEV1_R_2: R66.1, U18.6, U34.7
/Headset Audio Out Mux Switching/DEV1_R_3: R68.1, U19.6, U34.8
/Headset Audio Out Mux Switching/DEV1_R_4: R70.1, U20.6, U35.7
/Headset Audio Out Mux Switching/DEV1_R_5: R72.1, U21.6, U35.8
/Headset Audio Out Mux Switching/DEV1_R_6: R74.1, U22.6, U36.7
/Headset Audio Out Mux Switching/DEV1_R_7: R76.1, U23.6, U36.8
/Headset Audio Out Mux Switching/DEV2_L_0: R97.1, U7.5, U38.1
/Headset Audio Out Mux Switching/DEV2_L_1: R99.1, U8.5, U38.14
/Headset Audio Out Mux Switching/DEV2_L_2: R101.1, U9.5, U39.1
/Headset Audio Out Mux Switching/DEV2_L_3: R103.1, U10.5, U39.14
/Headset Audio Out Mux Switching/DEV2_L_4: R105.1, U11.5, U40.1
/Headset Audio Out Mux Switching/DEV2_L_5: R107.1, U12.5, U40.14
/Headset Audio Out Mux Switching/DEV2_L_6: R109.1, U13.5, U41.1
/Headset Audio Out Mux Switching/DEV2_L_7: R111.1, U14.5, U41.14
/Headset Audio Out Mux Switching/DEV2_R_0: R98.1, U16.5, U38.7
/Headset Audio Out Mux Switching/DEV2_R_1: R100.1, U17.5, U38.8
/Headset Audio Out Mux Switching/DEV2_R_2: R102.1, U18.5, U39.7
/Headset Audio Out Mux Switching/DEV2_R_3: R104.1, U19.5, U39.8
/Headset Audio Out Mux Switching/DEV2_R_4: R106.1, U20.5, U40.7
/Headset Audio Out Mux Switching/DEV2_R_5: R108.1, U21.5, U40.8
/Headset Audio Out Mux Switching/DEV2_R_6: R110.1, U22.5, U41.7
/Headset Audio Out Mux Switching/DEV2_R_7: R112.1, U23.5, U41.8
/Headset Audio Out Mux Switching/DEV3_L_0: R133.1, U7.4, U43.1
/Headset Audio Out Mux Switching/DEV3_L_1: R135.1, U8.4, U43.14
/Headset Audio Out Mux Switching/DEV3_L_2: R137.1, U9.4, U44.1
/Headset Audio Out Mux Switching/DEV3_L_3: R139.1, U10.4, U44.14
/Headset Audio Out Mux Switching/DEV3_L_4: R141.1, U11.4, U45.1
/Headset Audio Out Mux Switching/DEV3_L_5: R143.1, U12.4, U45.14
/Headset Audio Out Mux Switching/DEV3_L_6: R145.1, U13.4, U46.1
/Headset Audio Out Mux Switching/DEV3_L_7: R147.1, U14.4, U46.14
/Headset Audio Out Mux Switching/DEV3_R_0: R134.1, U16.4, U43.7
/Headset Audio Out Mux Switching/DEV3_R_1: R136.1, U17.4, U43.8
/Headset Audio Out Mux Switching/DEV3_R_2: R138.1, U18.4, U44.7
/Headset Audio Out Mux Switching/DEV3_R_3: R140.1, U19.4, U44.8
/Headset Audio Out Mux Switching/DEV3_R_4: R142.1, U20.4, U45.7
/Headset Audio Out Mux Switching/DEV3_R_5: R144.1, U21.4, U45.8
/Headset Audio Out Mux Switching/DEV3_R_6: R146.1, U22.4, U46.7
/Headset Audio Out Mux Switching/DEV3_R_7: R148.1, U23.4, U46.8
/Headset Audio Out Mux Switching/DEV4_L_0: R277.1, U7.12, U63.1
/Headset Audio Out Mux Switching/DEV4_L_1: R279.1, U8.12, U63.14
/Headset Audio Out Mux Switching/DEV4_L_2: R281.1, U9.12, U64.1
/Headset Audio Out Mux Switching/DEV4_L_3: R283.1, U10.12, U64.14
/Headset Audio Out Mux Switching/DEV4_L_4: R285.1, U11.12, U65.1
/Headset Audio Out Mux Switching/DEV4_L_5: R287.1, U12.12, U65.14
/Headset Audio Out Mux Switching/DEV4_L_6: R289.1, U13.12, U66.1
/Headset Audio Out Mux Switching/DEV4_L_7: R291.1, U14.12, U66.14
/Headset Audio Out Mux Switching/DEV4_R_0: R278.1, U16.12, U63.7
/Headset Audio Out Mux Switching/DEV4_R_1: R280.1, U17.12, U63.8
/Headset Audio Out Mux Switching/DEV4_R_2: R282.1, U18.12, U64.7
/Headset Audio Out Mux Switching/DEV4_R_3: R284.1, U19.12, U64.8
/Headset Audio Out Mux Switching/DEV4_R_4: R286.1, U20.12, U65.7
/Headset Audio Out Mux Switching/DEV4_R_5: R288.1, U21.12, U65.8
/Headset Audio Out Mux Switching/DEV4_R_6: R290.1, U22.12, U66.7
/Headset Audio Out Mux Switching/DEV4_R_7: R292.1, U23.12, U66.8
/Headset Audio Out Mux Switching/DEV5_L_0: R169.1, U7.11, U48.1
/Headset Audio Out Mux Switching/DEV5_L_1: R171.1, U8.11, U48.14
/Headset Audio Out Mux Switching/DEV5_L_2: R173.1, U9.11, U49.1
/Headset Audio Out Mux Switching/DEV5_L_3: R175.1, U10.11, U49.14
/Headset Audio Out Mux Switching/DEV5_L_4: R177.1, U11.11, U50.1
/Headset Audio Out Mux Switching/DEV5_L_5: R179.1, U12.11, U50.14
/Headset Audio Out Mux Switching/DEV5_L_6: R181.1, U13.11, U51.1
/Headset Audio Out Mux Switching/DEV5_L_7: R183.1, U14.11, U51.14
/Headset Audio Out Mux Switching/DEV5_R_0: R170.1, U16.11, U48.7
/Headset Audio Out Mux Switching/DEV5_R_1: R172.1, U17.11, U48.8
/Headset Audio Out Mux Switching/DEV5_R_2: R174.1, U18.11, U49.7
/Headset Audio Out Mux Switching/DEV5_R_3: R176.1, U19.11, U49.8
/Headset Audio Out Mux Switching/DEV5_R_4: R178.1, U20.11, U50.7
/Headset Audio Out Mux Switching/DEV5_R_5: R180.1, U21.11, U50.8
/Headset Audio Out Mux Switching/DEV5_R_6: R182.1, U22.11, U51.7
/Headset Audio Out Mux Switching/DEV5_R_7: R184.1, U23.11, U51.8
/Headset Audio Out Mux Switching/DEV6_L_0: R205.1, U7.10, U53.1
/Headset Audio Out Mux Switching/DEV6_L_1: R207.1, U8.10, U53.14
/Headset Audio Out Mux Switching/DEV6_L_2: R209.1, U9.10, U54.1
/Headset Audio Out Mux Switching/DEV6_L_3: R211.1, U10.10, U54.14
/Headset Audio Out Mux Switching/DEV6_L_4: R213.1, U11.10, U55.1
/Headset Audio Out Mux Switching/DEV6_L_5: R215.1, U12.10, U55.14
/Headset Audio Out Mux Switching/DEV6_L_6: R217.1, U13.10, U56.1
/Headset Audio Out Mux Switching/DEV6_L_7: R219.1, U14.10, U56.14
/Headset Audio Out Mux Switching/DEV6_R_0: R206.1, U16.10, U53.7
/Headset Audio Out Mux Switching/DEV6_R_1: R208.1, U17.10, U53.8
/Headset Audio Out Mux Switching/DEV6_R_2: R210.1, U18.10, U54.7
/Headset Audio Out Mux Switching/DEV6_R_3: R212.1, U19.10, U54.8
/Headset Audio Out Mux Switching/DEV6_R_4: R214.1, U20.10, U55.7
/Headset Audio Out Mux Switching/DEV6_R_5: R216.1, U21.10, U55.8
/Headset Audio Out Mux Switching/DEV6_R_6: R218.1, U22.10, U56.7
/Headset Audio Out Mux Switching/DEV6_R_7: R220.1, U23.10, U56.8
/Headset Audio Out Mux Switching/DEV7_L_0: R241.1, U7.9, U58.1
/Headset Audio Out Mux Switching/DEV7_L_1: R243.1, U8.9, U58.14
/Headset Audio Out Mux Switching/DEV7_L_2: R245.1, U9.9, U59.1
/Headset Audio Out Mux Switching/DEV7_L_3: R247.1, U10.9, U59.14
/Headset Audio Out Mux Switching/DEV7_L_4: R249.1, U11.9, U60.1
/Headset Audio Out Mux Switching/DEV7_L_5: R251.1, U12.9, U60.14
/Headset Audio Out Mux Switching/DEV7_L_6: R253.1, U13.9, U61.1
/Headset Audio Out Mux Switching/DEV7_L_7: R255.1, U14.9, U61.14
/Headset Audio Out Mux Switching/DEV7_R_0: R242.1, U16.9, U58.7
/Headset Audio Out Mux Switching/DEV7_R_1: R244.1, U17.9, U58.8
/Headset Audio Out Mux Switching/DEV7_R_2: R246.1, U18.9, U59.7
/Headset Audio Out Mux Switching/DEV7_R_3: R248.1, U19.9, U59.8
/Headset Audio Out Mux Switching/DEV7_R_4: R250.1, U20.9, U60.7
/Headset Audio Out Mux Switching/DEV7_R_5: R252.1, U21.9, U60.8
/Headset Audio Out Mux Switching/DEV7_R_6: R254.1, U22.9, U61.7
/Headset Audio Out Mux Switching/DEV7_R_7: R256.1, U23.9, U61.8
/Headset Audio Out Mux Switching/DEV_XBAR_CTL0: U7.1, U24.11
/Headset Audio Out Mux Switching/DEV_XBAR_CTL1: U7.16, U25.4
/Headset Audio Out Mux Switching/DEV_XBAR_CTL2: U7.15, U25.5
/Headset Audio Out Mux Switching/DEV_XBAR_CTL3: U8.1, U24.10
/Headset Audio Out Mux Switching/DEV_XBAR_CTL4: U8.16, U25.6
/Headset Audio Out Mux Switching/DEV_XBAR_CTL5: U8.15, U25.7
/Headset Audio Out Mux Switching/DEV_XBAR_CTL6: U9.1, U24.9
/Headset Audio Out Mux Switching/DEV_XBAR_CTL7: U9.16, U25.8
/Headset Audio Out Mux Switching/DEV_XBAR_CTL8: U9.15, U25.9
/Headset Audio Out Mux Switching/DEV_XBAR_CTL9: U10.1, U24.8
/Headset Audio Out Mux Switching/DEV_XBAR_CTL10: U10.16, U25.10
/Headset Audio Out Mux Switching/DEV_XBAR_CTL11: U10.15, U25.11
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

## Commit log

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2017-04-08 Added raspberry pi power connections and global power pins
    [power_handling.sch]
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2017-04-09 More work on audio/ptt mux circuits - split out each device input into own subsheet - decided on how ptt/mic mute is working - added power connections for mux/switch chips
    [audio-mux-control.sch, dev0-mux-conn.sch, dev1-mux-conn.sch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]
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2017-04-09 Some more muxing - finished all device sheets - connected all mux points on main sheet - connected power to 7400 series chips
    [audio-mux-control.sch, dev0-mux-conn.sch, dev1-mux-conn.sch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]
2017-04-09 Added data lines + connector pinouts
    Added connector pinout to each device sheet
    [audio-mux-control.sch, dev0-mux-conn.sch, dev1-mux-conn.sch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]
2017-04-09 Changing pinout of headset connectors - Changing to 8 pin connectors - adding bias voltage
    [audio-mux-control.sch]
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2017-04-09 Apparently adding sheets changes the sheet numbering on other sheets
    [usbc-support.sch]
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2017-04-26 Added fairchild library, SD card interface and started HDMI port
    [audio-mux-control.sch, dev0-mux-conn.sch, dev1-mux-conn.sch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]
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2017-04-27 Worked on power for USB and finished ESD for hdmi
    [power_handling.sch, raspbery-pi-headers-support.sch, usb-c-spi-flash.sch]
2017-04-27 Started fixing DRC issues
    [audio-mux-control.sch, dev0-mux-conn.sch, dev1-mux-conn.sch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]
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2017-05-04 Fixed power consumption value for IO expanders
2017-05-04 Finished first pass on power distro, annotated USB C controllers
    [audio-mux-control.sch, dev0-mux-conn.sch, dev1-mux-conn.sch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]
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2017-05-04 Started pcb layout, fixed some schematic issues
    [audio-mux-control.sch, edc-mux-board.kicad_pcb, usb-ethernet.sch]
2017-05-04 Updated crystal symbol and footprint and working on pcb layout
    [edc-mux-board.kicad_pcb, usb-c-power-supply.sch, usb-clocks-and-other-component-units.sch]
2017-05-05 Added all missing nonstandard footprints
    [audio-mux-control.sch, power_handling.sch, raspbery-pi-headers-support.sch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]
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2017-05-05 Fixing issues with pin numbering between footprint and symbol
    [raspbery-pi-headers-support.sch, usb-c-power-supply.sch]
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2017-05-11 Even more pcb layout stuff. almost finished one usb c controller
    [edc-mux-board.kicad_pcb, usb-c-power-supply.sch, usbc-support.sch]
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2017-09-28 removed all traces of USB C trickery from this branch
    [audio-mux-control.sch, dev0-mux-conn.sch, dev1-mux-conn.sch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]
2017-09-28 Made some more edits and fixed some part library issues
    [audio-mux-control.sch, dev0-mux-conn.sch, dev1-mux-conn.sch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]
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2017-09-30 Updating power + libraries
    - Reannotated all parts
    - Migrated to new OR gate library
    - Reorganized power sheet
    [audio-mux-control.sch, dev0-mux-conn.sch, dev1-mux-conn.sch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]
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2017-10-01 Updates during pcb layout
    Added more net labels
    moved switches and OR gates to +5V instead of +5VD
    [audio-mux-control.sch, dev0-mux-conn.sch, dev1-mux-conn.sch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]
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2017-10-01 Re arranging pins and component names
    to make pcb layout saner
    [audio-mux-control.sch, dev0-mux-conn.sch, dev1-mux-conn.sch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]
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2017-10-08 More pcb fixing
    [edc-mux-board.kicad_pcb, power_handling.sch]
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2017-10-13 Fixing power issues
    - Further separating analog and digital power lines
    - Making sure everything that is needed by the RPi is UPS backed.
    - Other general orginization and consolidation
    [audio-mux-control.sch, dev0-mux-conn.sch, dev1-mux-conn.sch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]
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2017-10-13 Started fixing power planes
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2017-10-13 Fixed Annotation issues
    [power_handling.sch]
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2017-10-13 Finally figured out why old net was hanging around
    [edc-mux-board.kicad_pcb]
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2017-12-15 Committing before the great restructuring of december 2017
    realized that the signal levels that I was planning on using are not
    supported by any of the switching chips I am using. Also fuck SPI.
    [audio-mux-control.sch, dev0-mux-conn.sch, dev3-mux-conn.sch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]
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2017-12-25 Added stereo amplifier sheet and stereo distribution amplifier sheet
    [audio-mux-control.sch, dev0-mux-conn.sch, dev1-mux-conn.sch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]
2017-12-25 Starting headset side rework
    [audio-mux-control.sch]
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2017-12-27 Adding 1:8 distro amps and 8:1 muxes for headset audio out connections
    [1-8-stereo-buffer-amp.sch, audio-mux-control.sch, dev0-mux-conn.sch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]
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2018-01-01 Finished headset side of mux up to device selector mux input connections
    - connected mixer output to subsheet
    [audio-mux-control.sch]
2018-01-02 The Start of the Great Restructuring Pt II
    - Removed all device connections from inside subsheets
    - Started reconnecting device muxes
    - general cleanup
    [1-8-stereo-buffer-amp.sch, audio-mux-control.sch, dev0-mux-conn.sch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]
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2018-01-19 Fixed vbat detect pullup resistors
    [power_handling.sch]
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2018-01-20 Starting reworking of power supply w/ dual rails
    [1-8-stereo-buffer-amp.sch, audio-mux-control.sch, edc-mux-board.sch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]
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2018-01-26 Fix non printing characters in descriptions
    [audio-mux-control.sch, headset-audio-out-mux-switching.sch, power_handling.sch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]
2018-01-26 Finished fixing power supply and starting pcb layout
    [1-8-stereo-buffer-amp.sch, ard-nano-hdr-ethernet.sch, audio-mux-control.sch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]
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2018-01-27 Fixing messed up reference numbers
    [1-8-stereo-buffer-amp.sch, audio-mux-control.sch, stereo-1-2-distro-amp.sch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]
2018-01-28 More updates
    - Changed 12V regulator to 3A version
    - Updated readme power calculations
    - Fixed which unit is used where on quad op amps
    - laid out stereo distro amplifier
    [1-8-stereo-buffer-amp.sch, edc-mux-board.kicad_pcb, power_handling.sch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]
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2018-02-01 Fixed 1:8 buffer amp unit mixup, placed more components
    [1-8-stereo-buffer-amp.sch, edc-mux-board.kicad_pcb, power_handling.sch]
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2018-02-02 Finished fixing 8:1 distro layouts
    [edc-mux-board.kicad_pcb]
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2018-02-02 Fixing op amp unit order
    [stereo-1-2-distro-amp.sch]
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2018-02-03 Fixed annotation errors of multi unit parts being swapped back to default
    [1-8-stereo-buffer-amp.sch, edc-mux-board.kicad_pcb, stereo-1-2-distro-amp.sch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]
2018-02-06 More attempts to fix multi unit part layout
    [1-8-stereo-buffer-amp.sch, audio-mux-control.sch, edc-mux-board.kicad_pcb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]
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2018-02-06 Removed some issues with 1:8 buffer amp schematic
    [1-8-stereo-buffer-amp.sch]
2018-02-06 Finally think I figured out the flipped units issue
    [1-8-stereo-buffer-amp.sch]
2018-02-06 Fixed multiple unit flipping issue.
    Removed extra unanotated components
    [stereo-1-2-distro-amp.sch]
2018-02-06 Fixing the unit issues here as well
    [stereo-amp.sch]
2018-02-06 Fixed traces after fixing unit swap issues
    [edc-mux-board.kicad_pcb]
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2018-02-07 Updated TS12A44514
    Changed unit mapping to allow for easier pcb layout
    Changed power supply from 12V to 5V to utilize the existing 5V power
    lane for the surrounding components
    [1-8-stereo-buffer-amp.sch, audio-mux-control.sch, edc-mux-board.kicad_pcb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]
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2018-02-07 Swapped pins on component to make layout easier
    [audio-mux-control.sch]
2018-02-07 More updates:
    Changed up the OR gate units to enable nicer trace routing
    Added ground planes for ESD diodes
    [audio-mux-control.sch, edc-mux-board.kicad_pcb]
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2018-02-08 Finished routing PTT muxes
    Changed order of ptt-xbar connections on IO expanders in order to
    simplify PCB layout
    [1-8-stereo-buffer-amp.sch, audio-mux-control.sch]
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2018-02-08 More pin swapping - 5-7 on R muxes
    [1-8-stereo-buffer-amp.sch, headset-audio-out-mux-switching.sch]
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2018-02-10 Fixing bypass capacitors and adding more power rails
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2018-02-10 Fixing unintentional connections
    [audio-mux-control.sch]
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2018-02-10 Fixed more connection issues
    [audio-mux-control.sch]
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2018-02-11 Swapped units on the SPST mute switches
    [1-8-stereo-buffer-amp.sch, audio-mux-control.sch]
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2018-02-16 Remove unnecessary parts of schematic to convert to daughterboard
    commit before importing netlist
    [1-8-stereo-buffer-amp.sch, ard-nano-hdr-ethernet.sch, audio-mux-control.sch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]
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2018-02-24 Fixed a few re annotation errors
    [headphone-mux.kicad_pcb]
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2018-02-24 Fixing more annotation errors and starting initial reroute
    [1-8-stereo-buffer-amp.sch, headphone-mux.kicad_pcb, headphone-mux.sch]
2018-02-24 Some preliminary finishing touches
    - working on final connector placement
    - added edge cuts layer
    - added edge keepout layer
    [headphone-mux.kicad_pcb]
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2018-02-25 Finished fixing mux sheet
    [mic-mux-control.sch, mic-mux.sch, stereo-amp.sch]
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2018-02-25 initial mic mux pcb layout stuff and changing text size in schematic
    [mic-mux.kicad_pcb, mic-mux.sch]
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2018-02-26 Finished routing board for now.
    Finalized positions of connectors and mouting holes, as well as board
    edge locations. DRC checks still need to be run
    [headphone-mux.kicad_pcb, headphone-mux.sch]
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2018-03-13 Reworked IO connections due to footprint mistakes
    [1-8-stereo-buffer-amp.sch, headphone-mux.kicad_pcb, headphone-mux.sch]
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2018-03-14 Finally figured out issues with b2b connectors.
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2018-03-16 Finished re alignment of left side of distro amps
    Starting re alignment of right side of distro amps
    My kingdom for asethetics
    [mic-mux.kicad_pcb]
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2018-03-20 Fixing db25 connector and routing headphone distribution connections
    [audio-mux-control.sch, motherboard.kicad_pcb, power_handling.sch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]
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2018-03-24 Fixed clearance issues with ethernet shield
    added cutout guides for mic mux board above
    [ard-nano-hdr-ethernet.sch, motherboard.kicad_pcb, motherboard.sch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]
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2021-07-19 Fixing language detection of kicad files
